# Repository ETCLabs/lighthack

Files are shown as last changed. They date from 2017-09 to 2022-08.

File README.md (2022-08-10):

# #lighthack
This repository contains the source and documentation for **#lighthack**, an educational project designed by ETC users and employees to engage with the DIY community.

#lighthack is a community-supported initiative, and your fellow #lighthackers are your first resource for help!

The #lighthack project is centered around Arduino-based hardware devices that users assemble from scratch. The Arduino connects via a USB COM port and then communicates via OSC with ETC's Eos software.

Eos supports this functionality on consoles running Windows 7 embedded or higher and ETCnomad for Windows in software version 2.6.1 and newer, and on ETCnomad for Mac in software version 2.7.0 and newer.

_Support for XPe-based consoles or XP computers is not planned for this project. If you do not know the version of embedded Windows your console uses, [check this link](https://support.etcconnect.com/ETC/Consoles/General/What_Version_of_Windows_is_my_Console_Running) for identifying information._

## test tools/usb_test
This is the first Arduino sketch to load - it helps to ensure that the Arduino is communicating successfully with Eos. This is also a good point to return to if you want to re-confirm the Arduino-Eos connection later on.

## #lighthack box 1
**#lighthack box 1** is a kit project with two encoders, three buttons and a 2x20 display. This kit is available for purchase directly from ETC's [US](https://shop.etcconnect.com/) and [EU](https://shop.etcconnect.eu/) online shops, but you can also find all of the parts directly from suppliers online. This project is located in the box_1 subfolder. This folder contains an assembly instructions document which also contains the parts list. It also contains the Arduino sketch and other supporting documentation.

[Supported OSC Commands](https://github.com/ETCLabs/EosSyncLib/blob/master/Supported%20OSC%20Commands.pdf)

## About this ETCLabs Project
#lighthack projects are designed to interact with ETC products, but they are not official ETC hardware or software. For challenges using, integrating, compiling, or modifying items in this project, we encourage posting on the [Issues page](https://github.com/ETCLabs/lighthack/issues) or on the [#lighthack forum](https://community.etcconnect.com/etclabs/f/lighthack). Again, #lighthack is a community-supported initiative, and the #lighthacking community is the best place to ask for help!

## Dependencies
Requires the Arduino OSC parsing library maintained by the great folks over at [CNMAT](https://github.com/CNMAT/OSC). The assembly instructions documents contain details on how to add this to your Arduino project.

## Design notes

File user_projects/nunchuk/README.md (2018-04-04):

#  Lighthack Nunchuk Assembly Instructions

<a href="http://www.youtube.com/watch?feature=player_embedded&v=b4YxDby04tY
" target="_blank">YouTube Video</a>

## Parts List

| **ETC PN** | **Vendor PN** | **Qty** | **Description** |
| --- | --- | --- | --- |
| 4201B9001 | Mouser 782-A000066 | 1 | Arduino Uno R3 |
| W6378 | | 1 | USB Cable, A to B |
| | Adafruit 342 | 1 | Nunchuk Remote Controller Attachment For Nintendo Wii |
| | Adafruit 345 | 1 | Nunchucky (Wii Nunchuck breakout adapter) |
| 4201B7001 | | 1 | Wire Solid Core 22AWG/0.65mm2 2-3&#39;/60-90cm |
| 4201A4001 | Hammond 1591U | 1 | Enclosure with lid and screws |

## Tools

- Wire strippers and cutters
- Soldering iron and solder

## Software

- Arduino Integrated Development Environment (IDE). Download from [https://www.arduino.cc/en/Main/Software](https://www.arduino.cc/en/Main/Software)
- Arduino sketch for Nunchuk. Download from [https://github.com/ETCLabs/lighthack](https://github.com/ETCLabs/lighthack)
- Arduino OSC library. Download from [https://github.com/CNMAT/OSC](https://github.com/CNMAT/OSC)
- Arduino to Eos Test Application. Download from [https://github.com/ETCLabs/lighthack](https://github.com/ETCLabs/lighthack)

## Test the Software

It is recommended that you test the Arduino before starting the assembly of the enclosure.

1. Download the source code from https://github.com/ETCLabs/lighthack, and extract the .zip file (or clone the repository if you're git-savvy!).

1. Open the Arduino USB Test sketch  (lighthackmaster\test\_tools\usb\_test\usb\_test\_sketch\usb\_test\_sketch.ino) in the Arduino IDE.
1. Before the sketch will compile, we need to add additional code (called a &quot;library&quot;) so that the Arduino knows how to speak OSC. Download the library as a .zip from [https://github.com/CNMAT/OSC](https://github.com/CNMAT/OSC).
1. In the Arduino IDE, select **Sketch &gt; Include Library &gt;Add .ZIP Library...** and select the OSC zip file you downloaded
1. Press the check mark to verify your sketch.

1. Connect the Arduino to your computer using the USB cable.
1. The Arduino IDE will automatically detect your Arduino Uno and select it. You can verify this in the Tools menu:

1. Press the arrow to upload your sketch to the Arduino.

1. After the sketch has been loaded, the Arduino&#39;s lights should have the L and ON lights solid and the TX light blinking once per second:

1. Launch Eos software, open Tab 99 Diagnostics, and look for messages that read:
```
        OSC USB Device Handshake Complete [OK]
        OSC USB Device Handshake Initiated [ETCOSC?]
```

The TX and RX lights should blink in sequence once per second.
Press `Incoming OSC` and you should see repeating messages of `[OSC Packet] /eos/ping` and a number counting up

These messages indicate that your Arduino and Eos are talking to each other.

The RX LED on your Arduino should also start blinking.

11. Exit the Eos software.
1. Now, load the main nunchuk.ino code. If you&#39;ve added the OSC library properly, the verification will be successful.
1. Press the arrow to upload your sketch to the Arduino.
1. After the sketch has been loaded, start Eos again and look for the same Handshake messages. Note that in this mode, the Arduino does not send the repeating Ping messages, and the Arduino&#39;s TX/RX LEDs will only blink once.

If text does not appear, follow the troubleshooting steps at [https://github.com/ETCLabs/lighthack/blob/master/box\_1/box\_1\_assembly\_instructions.pdf](https://github.com/ETCLabs/lighthack/blob/master/box_1/box_1_assembly_instructions.pdf)

## Adding the Nunchuk 

Connect the `3.3v` and `Gnd` pins to the respective Arduino Pins using the jumper wire and soldering iron. Connect Nunchuk `Data` to `SDA` (Analogue 4 on Arduino Uno) and `Clk` to `SCL` (Analogue 5 on Arduino Uno)
Breakout Adaptor
Wiring Diagram
Plug in the Nunchuk, and then powerup the Arduino

## Usage

Press Z as ETC Eos "Next" and C as "Last".

Use joystick to adjust Pan/Tilt on moving fixtures 

Hold down both Z & C for "fine" mode of movement

## Guide to Arduino LEDs



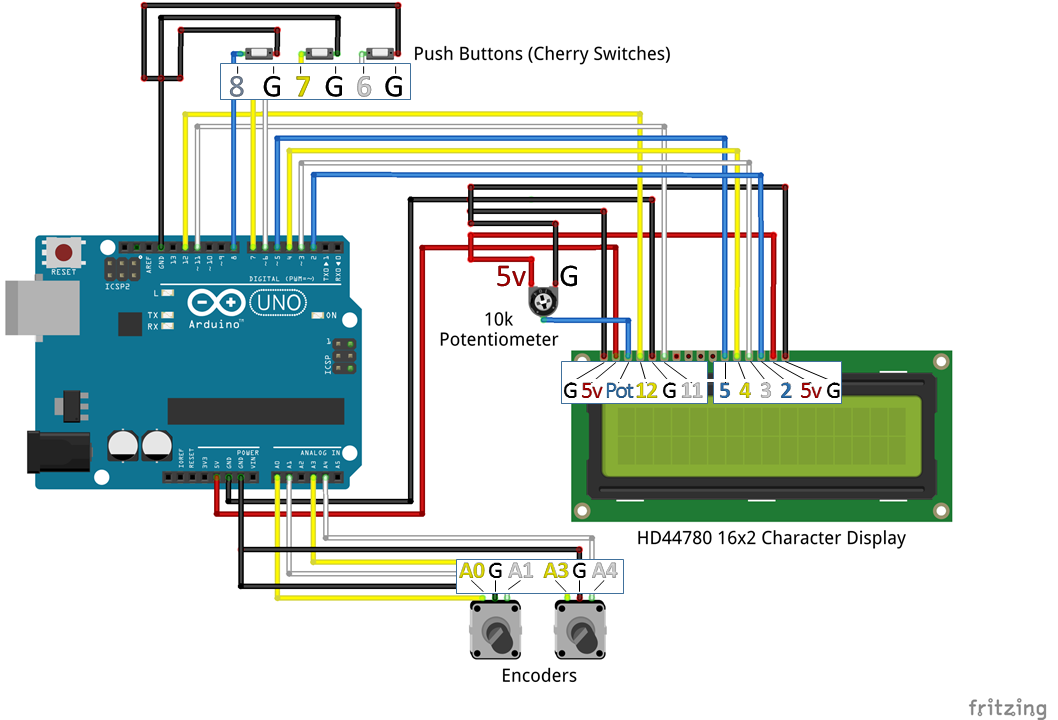
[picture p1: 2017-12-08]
box_1/Hookup_Diagram.png

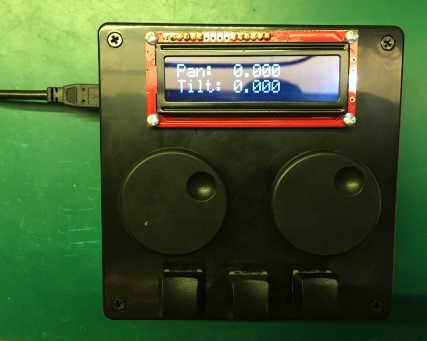
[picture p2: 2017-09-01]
box_1/Box 1.png

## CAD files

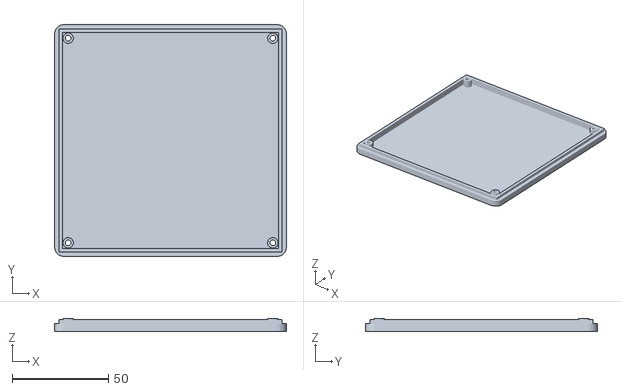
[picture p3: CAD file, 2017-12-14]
box_1/faceplate_model_blank.STL
120.4 x 120.4 x 6.50

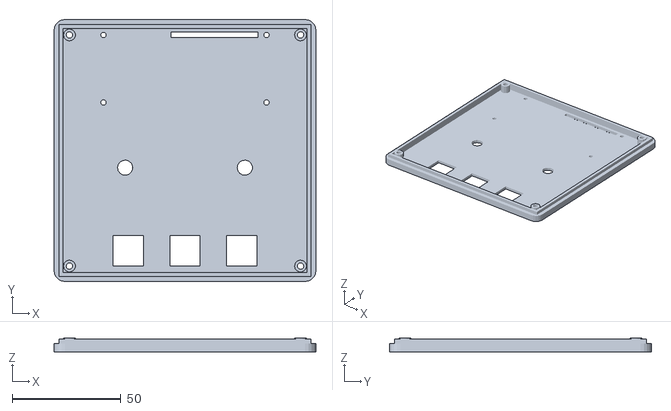
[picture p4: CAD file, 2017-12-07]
box_1/faceplate_model.STL
120.4 x 120.4 x 6.50

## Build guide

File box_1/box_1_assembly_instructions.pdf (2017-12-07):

#lighthack box 1 | | Revision: 07

## Assembly Instructions

Parts List

Part Number | Qty Description
4201B9001 | 1 | Arduino Uno R3
DS221-F | 1 | HD44780 Display Module
S846-F | 3 | Cherry MX Red Key Switch
4152A4039 | 3 | Black Eos® -Style Key Cap
L1243-F | 2 | Rotary Encoder with Panel Mounting Hardware
4201A4003 | 2 | Encoder Knob
4240B7011 | 1 | 10 kΩ Potentiometer
4201B7001 | 1 | Red Wire Solid Core 22AWG/0.65mm² 2-3'/60-90cm
4201B7002 | 1 | Black Wire Solid Core 22AWG/0.65mm² 2-3'/60-90cm
4201B7003 | 1 | White Wire Solid Core 22AWG/0.65mm² 2-3'/60-90cm
4201B7004 | 1 | Yellow Wire Solid Core 22AWG/0.65mm² 2-3'/60-90cm
4201B7005 | 1 | Blue Wire Solid Core 22AWG/0.65mm² 2-3'/60-90cm
J4630 | 3 | 5-position Wago Wire Connector
J4629 | 1 | 3-position Wago Wire Connector
W6378 | 1 | USB Cable, A to B
HW0006 | 10 | Machine screws #2-56x3/16" (~5mm)
HW9489 | 5 | Standoffs #2-56x1/4" (~6mm)
4201A4001 | 1 | Enclosure with lid and screws

Tools

Necessary:

- Wire strippers and cutters
- Soldering iron and solder
- Philips screwdriver
- Drill with 1
| /8" / 3mm,

1
| | /4" / 6mm,
| | 1 /2" / 12mm bits
- Rasp/File or Chisel

Helpful:

- Needle-nose pliers
- X-Acto knife or other sharp knife
- Electrical tape
- Thick double-sided tape

Software

- Arduino Integrated Development Environment (IDE). Download from https://www.arduino.cc/en/Main/Software
- Arduino sketch (code) for box 1. Download from https://github.com/ETCLabs/lighthack
- Arduino OSC library. Download from https://github.com/CNMAT/OSC
- Arduino to Eos Test Application. Download from https://github.com/ETCLabs/lighthack

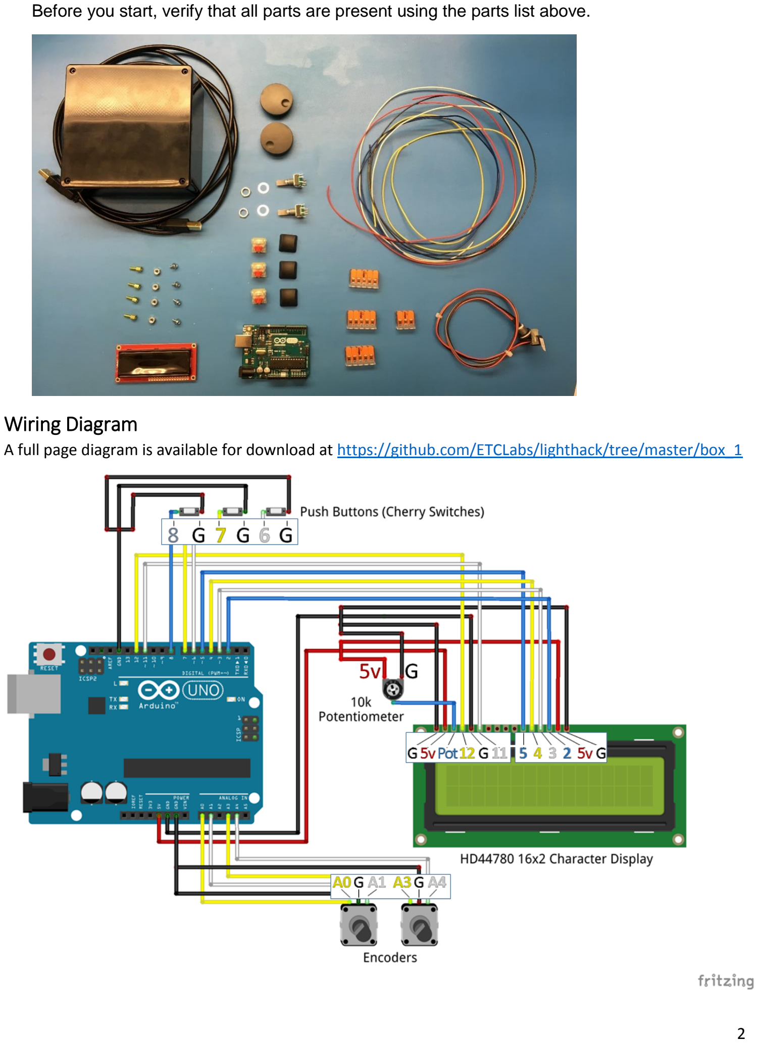
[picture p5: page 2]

Before you start, verify that all parts are present using the parts list above.

## Wiring Diagram

A full page diagram is available for download at https://github.com/ETCLabs/lighthack/tree/master/box_1

## Test the Software

It is recommended that you test the Arduino before starting the assembly of the enclosure.

1. Download the source code from https://github.com/ETCLabs/lighthack, and extract the .zip file (or clone the repository if you're git-savvy!).

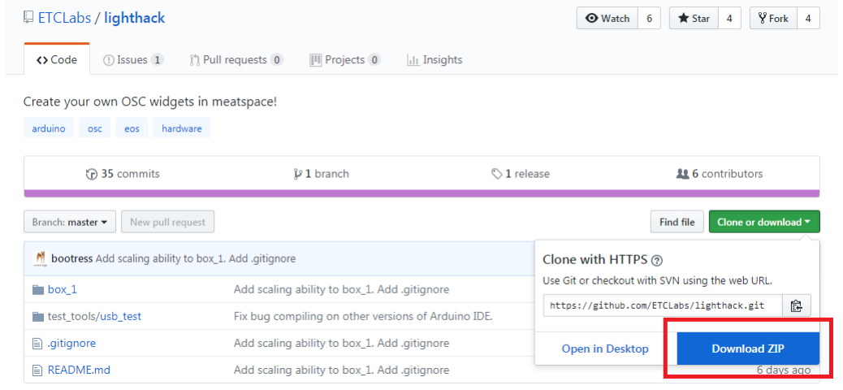
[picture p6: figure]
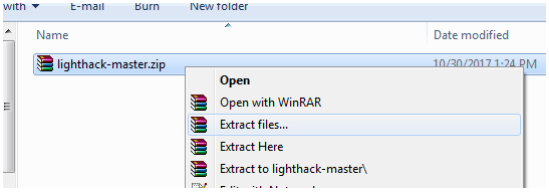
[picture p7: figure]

2. Open the Arduino USB Test sketch (lighthack-master\test_tools\usb_test\usb_test_sketch\usb_test_sketch.ino) in the Arduino IDE.
3. Before the sketch will compile, we need to add additional code (called a "library") so that the Arduino knows how to speak OSC. Download the library as a .zip
from https://github.com/CNMAT/OSC.
4. In the Arduino IDE, select Sketch > Include Library >Add .ZIP Library... and select the OSC zip file you downloaded
5. Press the check mark to verify your sketch.

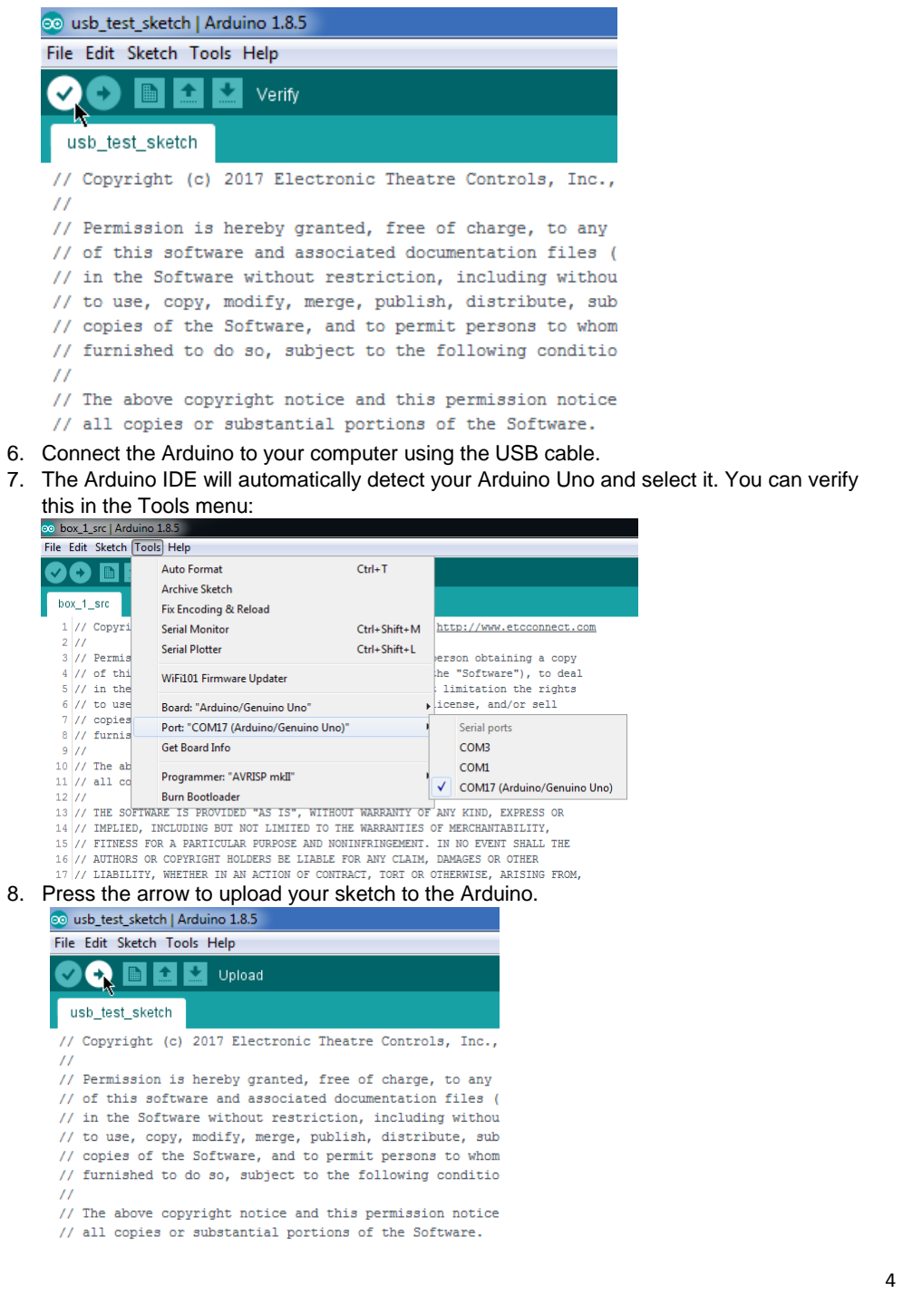
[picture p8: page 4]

6. Connect the Arduino to your computer using the USB cable.
7. The Arduino IDE will automatically detect your Arduino Uno and select it. You can verify this in the Tools menu:
8. Press the arrow to upload your sketch to the Arduino.

9. After the sketch has been loaded, the Arduino’s lights should have the L and ON lights solid and the TX light blinking once per second:

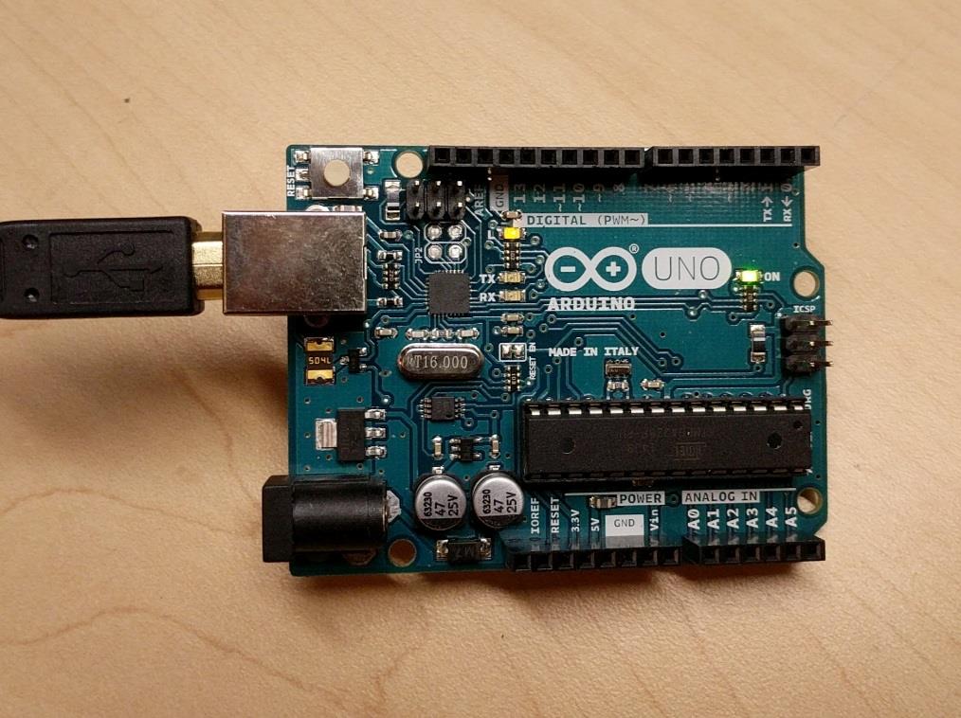
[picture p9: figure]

10. Launch Eos software, open Tab 99 Diagnostics, and look for messages that read:
“OSC USB Device Handshake Complete [OK]”
“OSC USB Device Handshake Initiated [ETCOSC?]”
The TX and RX lights should blink in sequence once per second. Press “Incoming OSC” and you should see repeating messages of “[OSC Packet] /eos/ping,” and a number counting up
These messages indicate that your Arduino and Eos are talking to each other. The RX LED on your Arduino should also start blinking.
11. Exit the Eos software.
12. Now, load the main box_1_src.ino code. If you've added the OSC library properly, the verification will be successful.

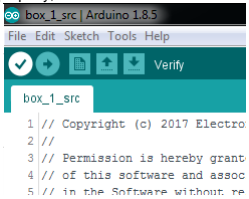
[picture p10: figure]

13. Press the arrow to upload your sketch to the Arduino.

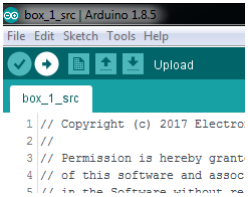
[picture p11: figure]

14. After the sketch has been loaded, start Eos again and look for the same Handshake messages. Note that in this mode, the Arduino does not send the repeating Ping messages, and the Arduino’s TX/RX LEDs will only blink once.
If text does not appear, follow the troubleshooting steps at the end of this document.

## Prepare the Enclosure

15. Print out the paper template, making sure to disable any "fit to paper" or scaling options so that it prints at actual size. The template is found at https://github.com/ETCLabs/lighthack/tree/master/box_1.
16. Cut out the template and lay it over the top of the enclosure lid, using the screw holes or tape to make sure it doesn't move.

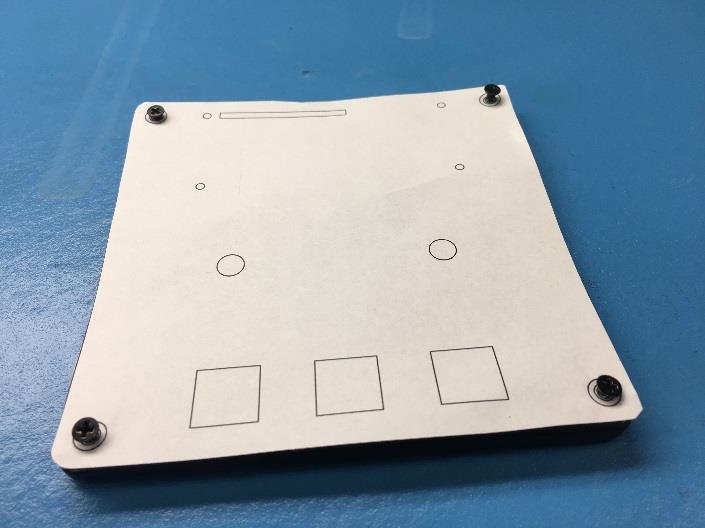
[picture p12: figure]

17. Drill out the holes using the proper size drill bits. Drill starter holes in the square cutouts. For the long rectangular slot, you may want to drill a few holes right next to each other as a starting point for a file.
18. Using this template, the LCD display will be mounted to the outside of the lid. Skip to Step 13 if you want to follow the template. If you would like to mount the display to the inside of the box, cut a rectangular hole in the enclosure lid slightly larger than the face of the LCD screen.

TIP: Don't feel like
drilling and filing? Use
the provided 3D
Printer template to
print a "pre-drilled" lid.

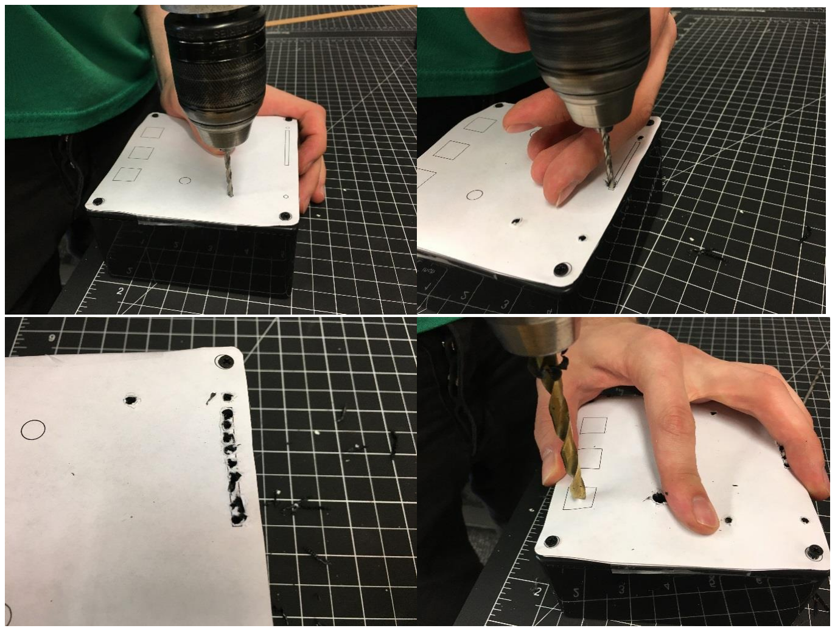
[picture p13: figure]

19. Using a square or rectangular file, file out the square holes and slot (or use your preferred method of making square holes).
20. Test fit the Cherry MX Red switches into the square holes as you file to make sure you have the right size.

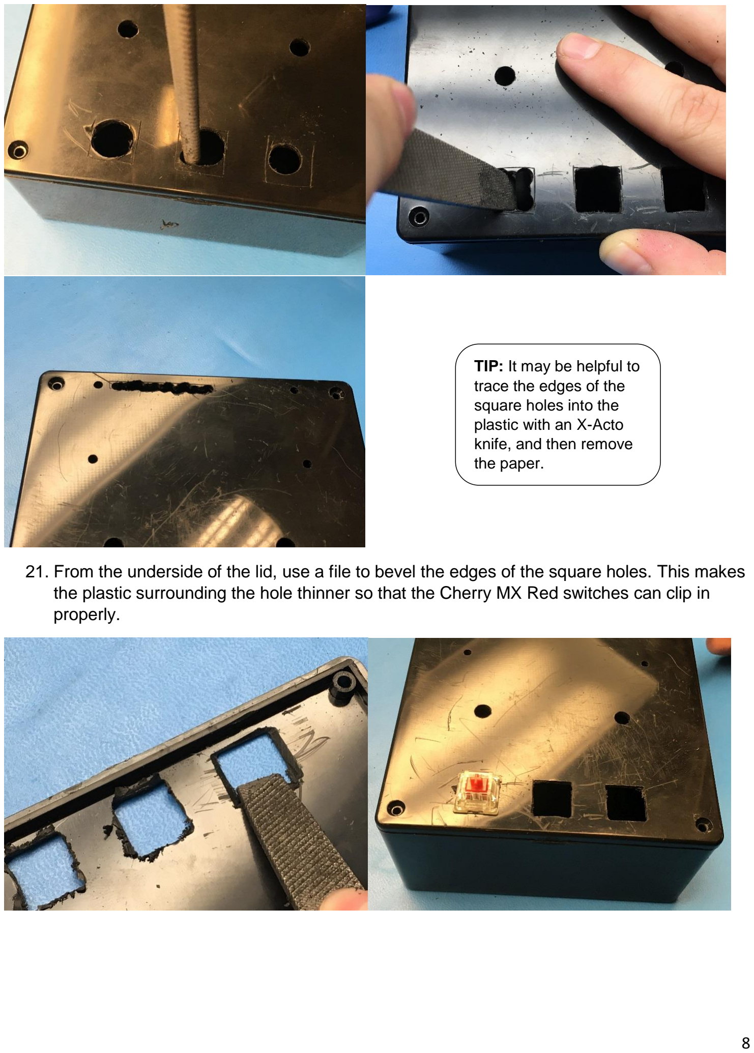
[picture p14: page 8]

21. From the underside of the lid, use a file to bevel the edges of the square holes. This makes the plastic surrounding the hole thinner so that the Cherry MX Red switches can clip in properly.

TIP: It may be helpful to
trace the edges of the
square holes into the
plastic with an X-Acto
knife, and then remove
the paper.

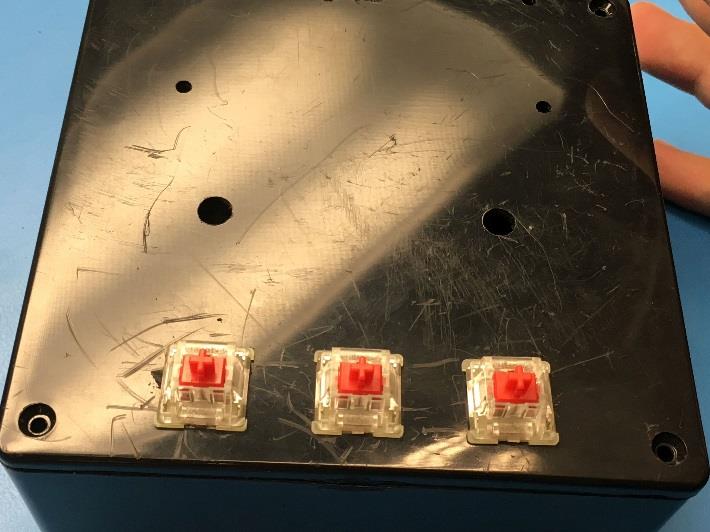
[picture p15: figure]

22. Line up the Arduino with a side of the box in order to estimate the location of the hole. We've found a good location to be 1"/25mm in from a corner and ½"/12mm up from the bottom. Use a ½"/12mm drill bit to drill a hole for the USB connector. Make sure you can connect a USB cable to your Arduino through the hole.
23. Drill a hole for the USB connector. If desired, add a second 1/2" hole to mount the potentiometer.

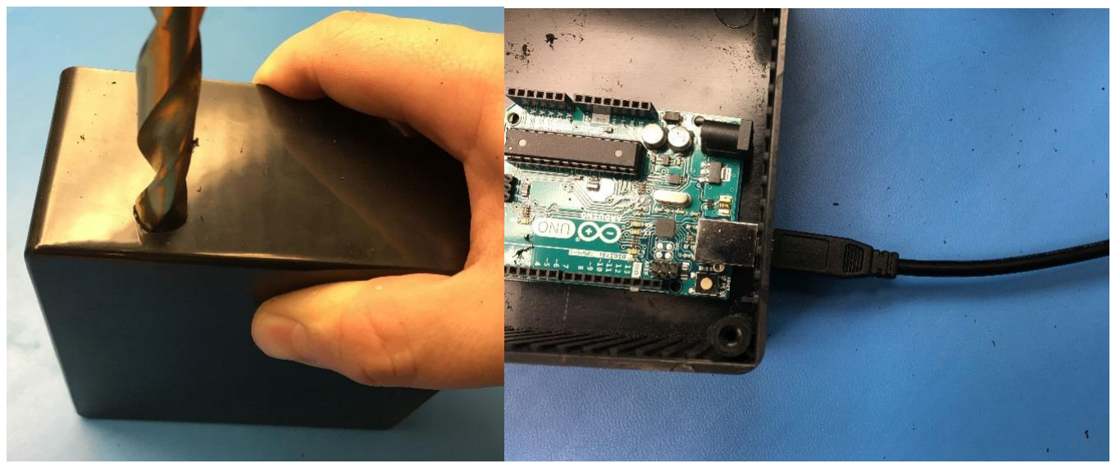
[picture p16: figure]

## Connect the Electronics

24. Cut appropriate lengths of wire to connect the three buttons and two rotary encoders to the Arduino as shown in the wiring diagram. The wire colors in the wiring diagram are a suggestion. The wire colors in your kit may vary.
25. Strip approximately ½"/12mm of insulation from either side of each length of wire.

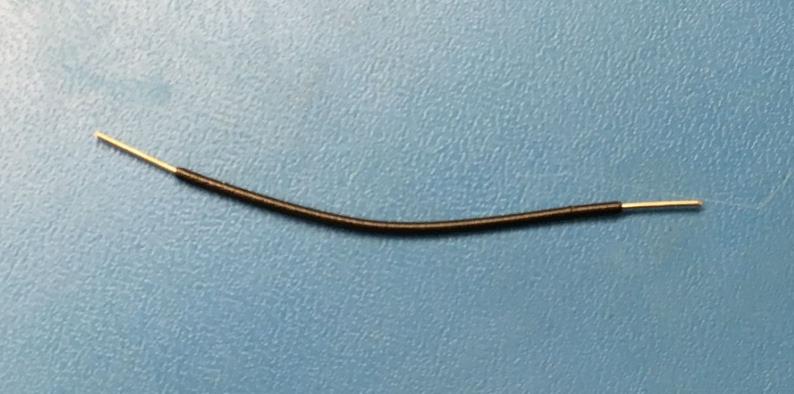
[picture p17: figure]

26. Solder one end of each wire length to pins on the rotary encoders and key switches.
27. Use the Wago connectors where multiple black (ground) wires need to be connected together. Only three of the five leads on the encoders need to be connected, as shown. You will want to have the key switches inserted into the enclosure lid already when you do this.

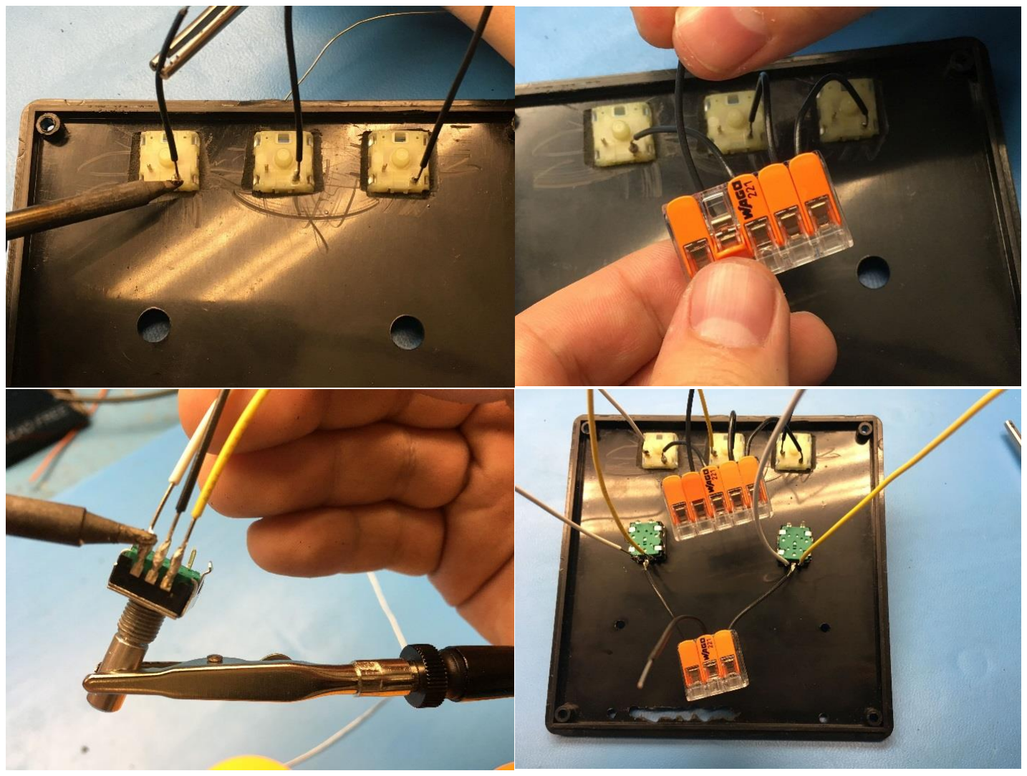
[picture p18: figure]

28. Cut appropriate lengths of wire to connect the display and contrast adjustment potentiometer to the Arduino as shown in the wiring diagram.
29. Cut off the connector from the potentiometer.

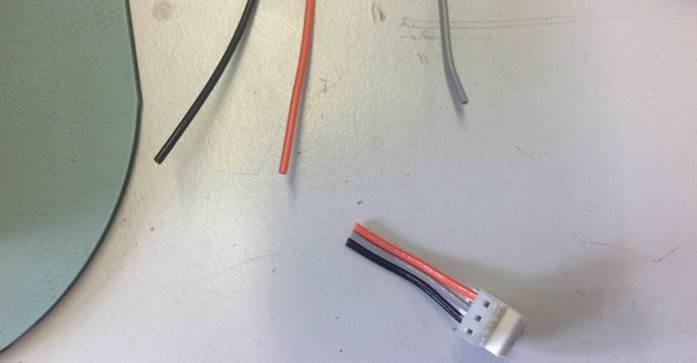
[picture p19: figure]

30. If you are mounting it to the box, thread on the rubber washer and locking ring, string the wire through the box, then tighten with the nut. This has to be done before soldering.
31. Strip approximately ½"/12mm of insulation from either side of each length of wire.
32. Solder one end of each wire length to the display as shown.
33. Connect the middle pin of the potentiometer to the display as shown.

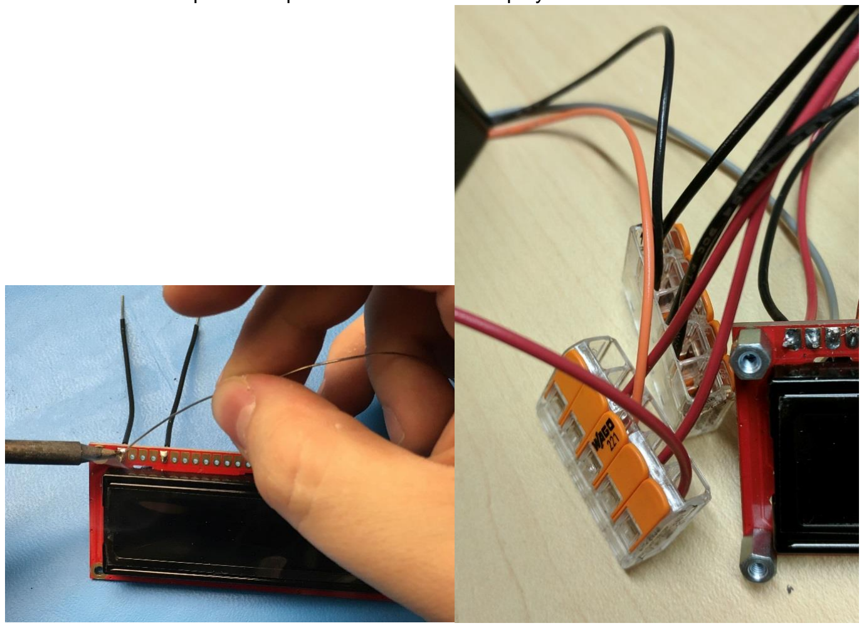
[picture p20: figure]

34. Connect the free end of each wire to the appropriate pin on the Arduino as shown in the wiring diagram.

35. Before mounting everything in the enclosure and finishing the assembly, the electronics should be tested. Connect the Arduino to a Win7 Eos Family console or a computer running ETCnomad.
36. Test the device by patching a moving light, selecting it and using the encoders to modify the pan and tilt values. Check to make sure that the "next" and "last" buttons cycle through the channels and the "fine" button switches between coarse and fine adjustment.

## Finish the assembly

Now that your module has been tested, it's time to put it in the enclosure.

37. Insert the two encoders through the holes from the inside of the lid.
38. Use the included panel mounting nuts and washers to secure the encoders.

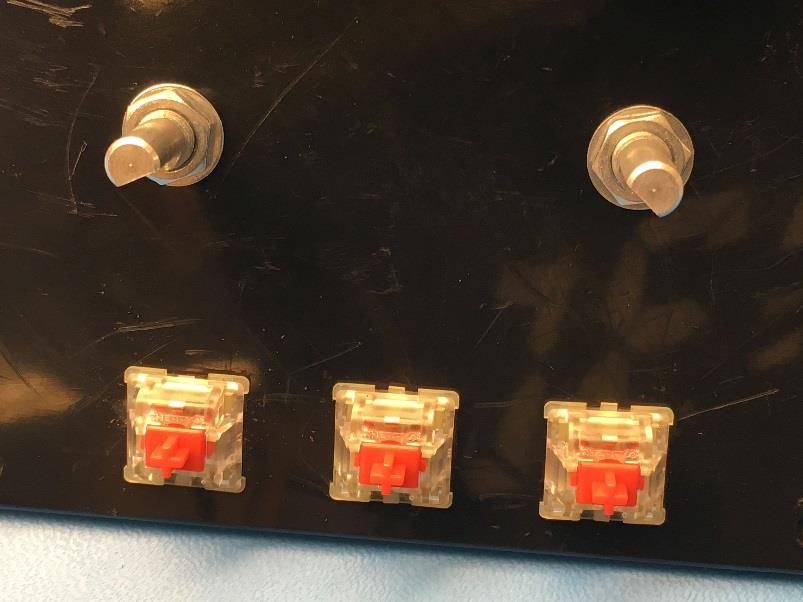
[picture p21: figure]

39. Disconnect the screen from the Arduino and feed its wires through the rectangular slot. If mounting to the inside of the box, you would instead mount the LCD screen inside the lid using the standoffs on the underside of the lid.

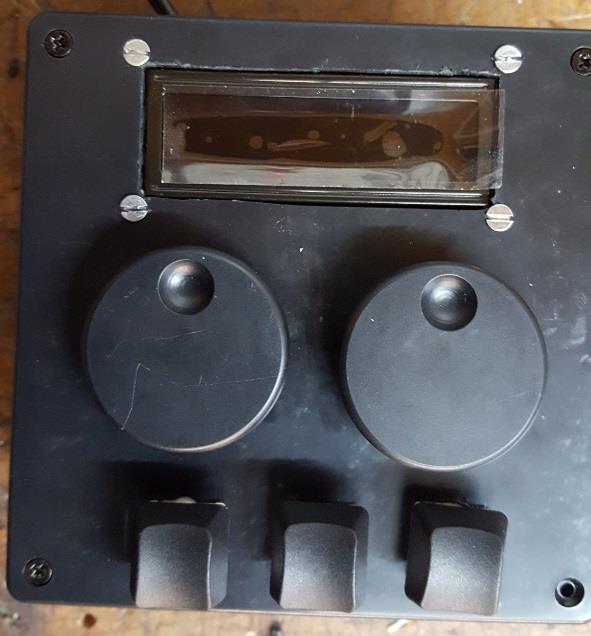
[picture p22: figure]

40. Secure the screen in place using eight #2-56 machine screws (four from the top, and four from the bottom) and either the ¼" (~6mm) or ½" (~12mm) standoffs. Extra screws and standoffs are provided.

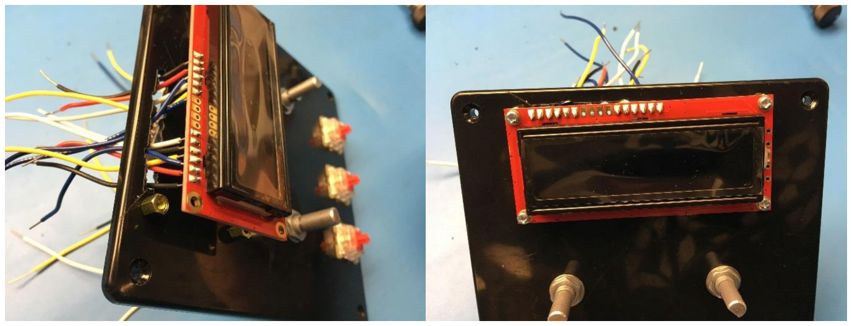
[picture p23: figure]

41. Place the Arduino into the enclosure such that the USB connector is aligned with the hole you drilled earlier.
42. Secure the Arduino using double-sided tape or your preferred method.

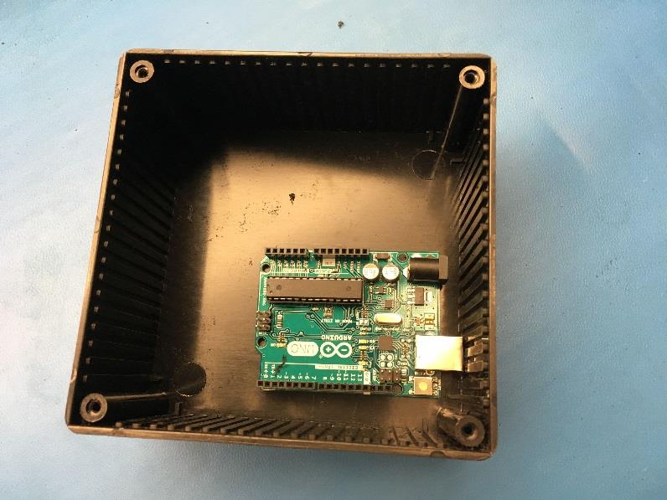
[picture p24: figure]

43. Reconnect all of the wires to the Arduino, referring to the wiring diagram.

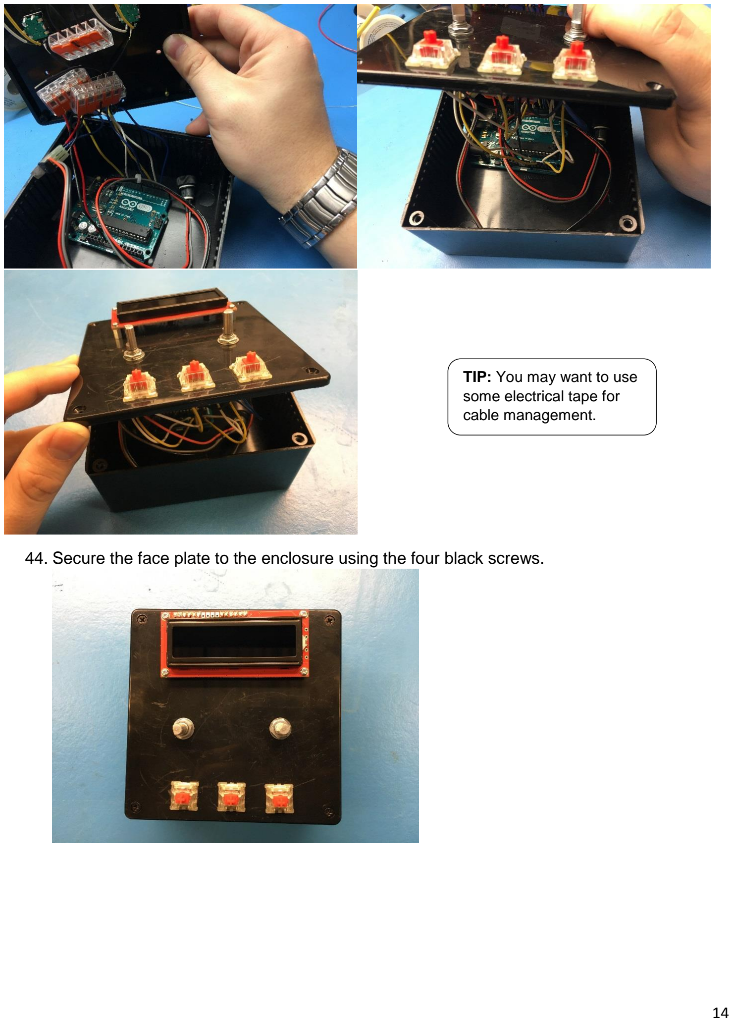
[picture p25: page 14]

44. Secure the face plate to the enclosure using the four black screws.

TIP: You may want to use
some electrical tape for
cable management.

45. Press-fit the keycaps and encoder finger wheels onto the key switches and encoders.

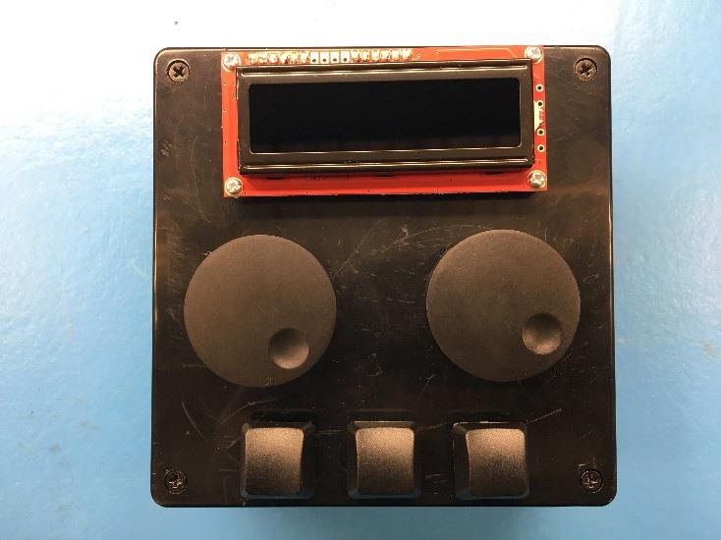
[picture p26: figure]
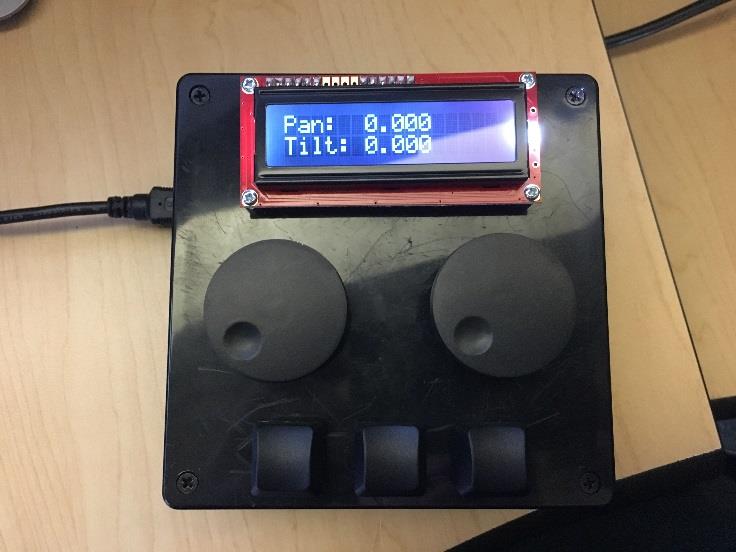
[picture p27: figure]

46. Re-test the module to make sure everything still works. Congratulations! You're done.

## Troubleshooting

Problem | Possible solution
Arduino software displays an orange error message when I try to verify using the check mark icon | Verify that the OSC library is installed using the procedure discussed in the Test the Software section.
Device mostly works but a button or an encoder is not working | Check the solder connections for cold or broken joints. Check the connections to the Arduino. Make sure the button or encoder is connected to the proper Arduino pins as shown in the wiring diagram.
One or both encoders are reversed | Look near the top of the source code (box_1_src.ino) for lines that say "#define PAN_DIR FORWARD" and "#define TILT_DIR FORWARD". To reverse the direction of an encoder, set the corresponding line to REVERSE, i.e. "#define PAN_DIR REVERSE".
Screen "glitches" or displays strange characters | Check the screen's solder connections for cold joints. Check the screen's connections to the Arduino. Make sure no connections are loose or disconnected and that the connections are as shown in the wiring diagram.
Screen is all black or all white | Make sure the contrast potentiometer is connected to the screen as shown in the wiring diagram. Make sure the Arduino is powered on and the code is loaded. Arduino power can be verified by a green "ON" LED located next to the Arduino UNO logo. Turn the contrast potentiometer until text displays on the screen.
Device is not recognized by Eos Family device | Make sure the version of Eos or ETCnomad software you are running supports OSC-over- USB. Make sure the Arduino driver pack is installed on the device running ETCnomad software. Use the usb_test (https://github.com/ETCLabs/lighthack/tree/master/test_tools/usb_test) sketch from the Github repository to narrow the problem.

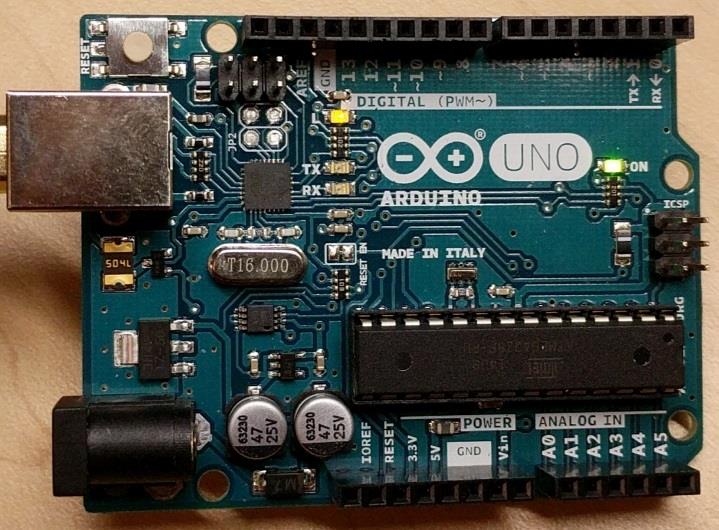
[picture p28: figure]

## Arduino LED Guide

LEDs to be aware of:
- ON (green): power presence
- L (amber): presence of code
- TX (amber): transmitting data
- RX (amber): receiving data
When you plug the Arduino in for the first time:
- On: solid
- L: possibly blinking
- TX: off
- RX: off
When you are loading sample or test code to the Arduino:
- On: solid
- L: will go off
- TX: flashing then solid
- RX: flashing then solid
When you have loaded the USB test sketch, but are not connected to a compatible Eos Family device:
- On: solid
- L: solid
- TX: heartbeat
- RX: off
When you have loaded the USB test sketch, and are connected to a compatible Eos Family device:
- On: solid
- L: solid
- TX: heartbeat
- RX: hearbeat
When you have loaded the Box 1 sketch, but are not connected to a compatible Eos Family device:
- On: solid
- L: will go off
- TX: flashing then solid
- RX: flashing then solid
When you have loaded the Box 1 sketch, and are connected to a compatible Eos Family device:
- On: solid
- L: solid
- TX: flashes when you move pan/tilt or hit next/last on the box
- RX: flashes when you move pan/tilt on Eos Family device

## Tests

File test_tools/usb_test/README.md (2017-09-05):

# USB Test Sketch
This folder contains a troubleshooting tool to verify the line of communication between an Arduino and the Eos software. Once connected with Eos, it sends a series of OSC "ping" messages which are visible in the Eos diagnostics tab. Follow these steps to use it:

1. Burn the sketch to your Arduino using the Arduino IDE.
2. Start the Eos Family software, and connect your device to the machine running Eos (if not the same machine).
3. Navigate to the Eos diagnostics tab ([Tab & 99]). You should see log messages about an OSC handshake completing:

handshake messages

4. On the diagnostics tab, click the button labeled "Incoming OSC (off)" to turn on display of OSC messages. You should see a ping message coming from your device once per second with an incrementing number argument:

ping messages

If this doesn't work, there is a non-hardware-related problem. Make sure the Arduino USB drivers are installed on your target machine. Check the Device Manager to make sure the Arduino is being recognized correctly.

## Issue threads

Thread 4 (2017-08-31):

Can't get anything to work

jpgagnon73, 2017-08-31:
So, I've wired it all up, several times.  Loaded the sketch with OSC library several times, no errors.  I only get 1 line of squares on the display and not one ounce of control.  I am running an Uno.  is v3 vital to this project working?  Is there something missing in the code??
Thanks
JP

bootress, 2017-08-31:
:confused:

We have tested the code as it exists here with Nomad PC and several consoles. Note that there is no support for Nomad Mac yet. Some things to try:

- Troubleshooting section at the end of the assembly instructions document
- Watch the Eos logs ([Tab] & 99) when you connect the Arduino to the console. You should see messages scroll by that look similar to:
  - OSC USB Device Connected (Handshake Required)
  - OSC USB Device Handshake Initiated [ETCOSC?]
  - OSC USB Device Handshake Complete [OK]

  This will verify that basic OSC USB connectivity is working between the device and the Eos software. Then you'll know that it's a hardware/wiring issue.

 I took a look at the differences between Uno original, R2 and R3 [here](http://startingelectronics.org/articles/arduino/uno-r3-r2-differences/); We tested on an R3, but I see nothing that would make the code function differently on an R2 or earlier.

jpgagnon73, 2017-08-31:
Ok, well I've been doing it on a mac only at this point.  i will try on my dedicated nomad PC at home.  one question, does the display show anything until it connects to EOS?

jpgagnon73, 2017-08-31:
And I just verified that the UNO i'm using is an R3.  Sometimes I need to open my eyes more.

bootress, 2017-08-31:
Yes, if there is no Eos connection there should be a default display which looks like:

```
Pan:  0.000
Tilt: 0.000
```

If you are getting a line of squares, I strongly suspect a wiring issue. Double check the wiring and especially the solder joints (cold solder joints tripped us up once while we were testing).

jpgagnon73, 2017-08-31:
yeah, I just get squares.  I am going to resolder the whole thing.  Curious, can the display be tweaked to show
              PAN          TILT
            0.000         0.000

I think this would make more sense in terms of the layout of the encoders.  Also, any reason we could use the encoder push down function to toggle the fine/coarse?

bootress, 2017-08-31:
The beauty of this being a DIY project is that you can make it do whatever you want! Our code is just a guideline / jumping off point. Your changes are totally doable with just a few tweaks to the code (the encoder push down change might require some new wiring too).

jpgagnon73, 2017-08-31:
I am hoping it will be easy to change the text.  i would love to make this a 3 encoder box, so it will be more useful to mod to do other ML attributes down the road.  Thanks for your hard work on this.  Hopefully I can get it all working once I re-solder it all.

bootress, 2017-08-31:
Glad to help, and good luck! I'm told there will soon be a forum dedicated to this project on the ETC Community, so when that goes live I encourage you to post your modifications so other DIYers can take note!

Closed 2017-08-31.

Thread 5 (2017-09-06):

Some Arduino hardware not working.  Various responses

Druuka, 2017-09-06:
USB OSC Arduino Device List

Arduino Uno Genuine			Yes
Osepp Uno R3 Plus			Does not see USB device
Arduino 101 Genuine			No
Arduino Ethernet with Arduino FTDI 	Yes
Arduino M0				Sees as USB Serial device but M0 not handshaking
Arduino Due				Tries to handshake on programming port but Due tries on native port
Generic Nano ATMega328			Does not see USB Device
OSEPP Nano ATMega328			Does not see USB Device
Gravitech Nano ATMega328		Does not see USB Device
Teensy 3.2				Does not See USB Device
Arduino ATMEGA2560			Yes

bootress, 2017-09-06:
Thank you so much for doing this testing. To add the additional context from your facebook comment, these are results from testing on an Ion Win7 console, right?

I found out that we are only installing a subset of the Arduino driver pack onto our consoles with the new Eos versions. This is probably the reason for your "Does not see USB Device" results. I am going to see what we can do about this in the future.

Druuka, 2017-09-06:
Yes this was with a Windows 7 based Ion console for testing.  I agree.  It would be great if they could include at least a couple others.  Something small like the Nano or Mini/pro mini or micro.  The Teensy line are also very popular because they are fast and very versatile.  Some of the more obscure (101, M0, Due) are nice units but not part of the core arduino that people own. Most of the Generic/non arduino brand units use the FTDI232 chipset which is its own set of drivers.

sstaub, 2017-09-06:
Many Arduino clones and ESP32 boards uses the CH340g USB chip, drivers can found on [http://sparks.gogo.co.nz/ch340.html](url). The last updates of the OSC library was done a year ago and only teensy boards were updated. The newer arduino boards with atmel samd21 (e.g. Arduino Zero) are not supported yet.

sstaub, 2017-09-06:
I tested following boards on WIN10 (Apple MacBook with Parallels and Bootcamp)
- Arduino UNO original OK
- Arduino Nano Clone with FTDI OK
- Arduino Nano Clone with CH340G OK
- Arduino Micro Clone (native USB) OK
I will test some other boards next time and report the results.

Druuka, 2017-09-06:
sstaub,
Did you install drivers for those on the computer?  If so they may not work with a console.  I think we need to get a list of what works with the default drivers provided with the console.

sstaub, 2017-09-06:
Yes, I installed the driver for my macOS (I use PlatformIO for coding on my MacBook) and WIN10
for use with ETCnomad.
I don't know if the drivers work on the console, but if you look on ebay or aliexpress you find many boards who use the cheaper CH340G USB chip instead of the FTDI chip. So maybe etc will install also this driver on the consoles.

Druuka, 2017-09-06:
I'm trying to come up with a list of what does and doesn't work with the default drivers so ETC can decide what additional drivers they want to install on the consoles.  For Nomad users they can install whatever drivers they want. :)

jpgagnon73, 2017-09-07:
So, I just tried testing mine on an Element XP console and it does not work.  such a bummer.  But at least it works with Nomad.

jpgagnon73, 2017-09-26:
I can confirm the Arduino Nano works on Nomad if you install the specific driver for for it on the console.  This will work for my scenarios very well.

kcrayn, 2017-12-08:
I'm trying to get a Genuino Micro working with Nomad under Win10 but not having any luck. It works perfectly using an UNO. Do I need to change anything in the code (I'm specifically trying to get the usb_test to work)

sstaub, 2017-12-09:
Working with an micro clone without problems, have WIN10 recognized your micro. Will see it by nomad (open tab 99 for analyzing).
Have also a look to the new #lighthack forum.
[https://community.etcconnect.com/etclabs/f/lighthack](url)

kcrayn, 2017-12-11:
I didn't realize there was a #lighthack forum, I've made a post over there with more details.
Thank you

TfairleyHO, 2018-05-04:
I am trying to use a SparkFun "RedBoard" that I got for free with a class I took, but when running the test sketch I can get Nomad to recognize the USB but it won't receive the OSC message. I tried plugging it into our Element (win7) but it would not even recognize the usb device. The redboard has an ATMega328p and FTDI1533. I thought it would work fine since it is supposed to be very similar to the UNO. This might be the wrong thread to post this but I thought it was a hardware issue related to the main topic. Let me know if anyone has any ideas.

Druuka, 2018-05-04:
TfairleyHO,   If you look at my post above I couldn't get any of the atmega328 based boards to be recognized by the console.  The console identifies boards based on how the USB/Serial connection is created Some of the devices show up as a usbserial rather than serial and these seem to be the units that the console is not attempting negotiations with.

sstaub, 2018-05-04:
Maybe it is the driver, maybe it is a problem with the VID/PID of the the board.

TfairleyHO, 2018-05-07:
So I managed to change the PID/VID using the FT-Prog tool from FTDI. I changed it to match the PID/VID for the Uno but I still needed to change the PID/VID in the FTDI driver and force it to use that driver since it wouldn't work with the UNO driver. The main difference seems to be that the Uno uses the FT232RL FTDI chip but the RedBoard uses the FT231XS Chip.

I can successfully upload the Handshake test, and now Nomad seems to recognize it as an OSC device since it puts out a lot of OSC strings. Now however it is giving me the following error multiple times: "Read Failed with result 17, error 0x1". Then it ends with EOS attempting the Handshake but receives nothing in return. I feel like I am closing in on a solution but still need some help. There is a field in the FT-Prog tool to change the Manufacturer from it's default (FTDI) in the EEPROM. Maybe I need to change that. Not sure what is causing EOS to fail out but it must have something to do with the different FTDI chips.

sstaub, 2018-05-07:
Have you changed the PID/VID also in the boards.txt of the Arduino IDE?
I have had also problems with FTDI chips and their clones, sometimes they work sometimes not.
Maybe the driver will be overridden when you install the console software.
Best way seems to use chips with native usb, like Arduino Mikro etc. because
they work without any external driver on newer systems.

TfairleyHO, 2018-05-07:
The PID/VID on the EEPROM and the Driver now match the PID/VID in boards.txt so the IDE now recognizes it as an UNO. I don't really see how changing boards.txt would affect how EOS interacts with it anyways. I wonder if I need to modify the UNO driver to work with this chip, or vice versa edit the FTDI driver so that it acts like an UNO. Has anyone had experience with boards using the FT231XS?

TfairleyHO, 2018-05-08:
What driver do you use for your nano-clone, and what PID/VID doe the Nano use? I am especially interested in the Clone using FTDI. If I switch the PID/VID to the UNO I can get EOS to recognize it as an OSC device but it doesn't seem to be able to communicate over USB with it. I have a few other things that I am going to try and I will let you know what happens.

TfairleyHO, 2018-05-08:
Anyone know if there is a specific list of PID/VIDs that Eos will listen too?

benjaminauer, 2022-09-15:
Cant get this working with Arduino Leonardo.
No handshake. Eos 3.1.3

sstaub, 2022-09-15:
@benjaminauer I think Leonardo will not work on Windows.  Only Arduino UNO and MEGA is supported official.

benjaminauer, 2022-09-16:
@sstaub you are right. UNO works just fine.
do you know if a request for more support was every brought to etc?
and you know that Leonardo / atmega32u4 works on mac systems?

sstaub, 2022-09-17:
I can remember that 32u4 boards works on macos.
There was an EOS feature request for supporting Teensy and Raspberry Pi Pico boards. On macos I prefer Raspberry Pi Pico boards using https://github.com/earlephilhower/arduino-pico
with the master branch of the OSC library which supports the board.

benjaminauer, 2022-09-17:
Thanks for the hint.
I am looking for the smallest formfactor, thats why i tried the atmega32u4 based dfrobot beetle.
will possibly try the beetle RP2040.
my teensy did work with NOMAD windows 10 but not GIO windows 7. ever had succes with a pico board and GIO windows7?

sstaub, 2022-09-17:
On consoles only Arduino UNO and MEGA definitely works. Maybe other boards works on consoles which works with Windows 10 like Apex and newer Element 2, but this is not tested. Maybe I work on the new Apex consoles in November were I can try.

jamiejcole, 2023-10-28:
Any update on this? I have a win7 element 2 console and my arduino uno clone is not being recognised at all in diagnostics page. It's using the CH340 chipset, really struggling to get this to work. Is there any way i can install the drivers onto the console?

sstaub, 2023-10-28:
@jamiecole No! Use an Original Arduino UNO or MEGA.

jamiejcole, 2023-10-29:
> Any update on this? I have a win7 element 2 console and my arduino uno clone is not being recognised at all in diagnostics page. It's using the CH340 chipset, really struggling to get this to work. Is there any way i can install the drivers onto the console?

Update on this, was able to install the correct drivers by:
- loading into the console ECU,
- spamming shift to open the sticky keys menu
- clicking the hyperlink on the prompt to open control panel
- open device manager from control panel
- find the COM port for the Arduino
- insert usb with extracted .zip folder for windows 7 CH340 drivers, downloaded from [this page](https://www.wch-ic.com/downloads/CH341SER_ZIP.html)
- click update drivers
- select update from local file
- find extracted driver folder on USB
- install drivers
- exit out of all windows and launch EOS primary
- COM4 port is now recognised and can talk to Arduino via OSC over USB

sstaub, 2023-10-30:
@jamiejcole Yes, you can install driver on your console, but it is possible that you will loose your warranty.

geocom, 2025-02-27:
Have found the fix for Teensy 4's on etc consoles. Takes a bit more than the Teensy 3.2 and testing is not helped by windows caching the device so if this doesn't work for you, you may need to look into changing the serial number this is because of how the consoles are locked down you cant remove the cache(at least I couldn't as you cannot get administrator level access) so the only option is to change the serial number as you need the PID/VID to remain the same.

Changes below.
usb_desc.h
PID/VID needs to change lines as per normal for a teensy 3.2
NUM_INTERFACE needs to be changed to 2
EXPERIMENTAL_INTERFACE need to be commented out

usb.c
Uncomment
//USB1_PORTSC1 |= USB_PORTSC1_PFSC; // force 12 Mbit/sec

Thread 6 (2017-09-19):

Simpler LCD Screen

jpgagnon73, 2017-09-19:
I would love to try and use the 16x2 display from this link here:  http://wiki.sunfounder.cc/index.php?title=I²C_LCD1602#Step_3:_Copy_the_code

This uses Pins A4 &A5 for all data to the lcd instead of D2-5 +D11+12.  Much simpler build.  But I'm having problem getting it to work in the sketch.  Any help would be greatly appreciated.

I know I would have to change the Encoders to use Pins A0+A1 and A2+A3  (not sure why A2 and A5 were originally used in the sketch since nothing is connected to them physically.)

JP

bootress, 2017-09-19:
Looks like you will need to download and include the LiquidCrystal_I2C library (seems to be a separate library from the LiquidCrystal one we use)

> (not sure why A2 and A5 were originally used in the sketch since nothing is connected to them physically.)

I think it's cruft that was originally intended to read the encoder's pushbutton, which we ended up not using in our example. I'll rip that out in the next update. For a quick fix, you can probably simply move the second encoder to pins A2+A3, and change lines 452 and 453:
```Arduino
initEncoder(&panWheel, A0, A1, 9, PAN_DIR);
initEncoder(&tiltWheel, A2, A3, 10, TILT_DIR);
```
9 and 10 are just two unused pins in the example. Then follow their instructions for including the LiquidCrystal_I2C library and copy their example code for initting the LCD (disclaimer: I have not tested this)

jpgagnon73, 2017-09-19:
When putting it into the sketch I kept getting errors like VOID already defined or other things.  I got it to work on it's own from the sample sketch they provided.  Something I'm missing I guess and not sure where to look.

jpgagnon73, 2017-09-20:
OK, found my issues.  Mostly it was where I was putting the Init LCD Code.  Found the correct placement where the original was.  And thanks for the InitEncoder change.  That workaround should work great.  This also works with the 20x4 version of this display as well, just need to setup the display for those parameters.  Now, what to do with the extra screen real estate.

Closed 2017-10-14.

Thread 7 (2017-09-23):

xp machines not functioning

Druuka, 2017-09-23:
Per a discussion with Matt Pumplin on the ETC forums I think we should include this info on the readme.
I should also note that OSC over USB is not implemented / supported for Windows XP consoles and computers.

jpgagnon73, 2017-09-23:
Will XP machines ever be supported for USB/OSC?  It's a real shame to all the legacy consoles out there to not have this functionality, especially the Element owners out there.

bootress, 2017-09-25:
@MizPlusPlus can you weigh in on prospects for future XP support, before I update the README?

bootress, 2017-09-26:
I've been told Windows XP support is not planned for this project. I'll update the README shortly to reflect that.

Don't forget that [Element consoles are eligible for upgrade to Windows 7](http://www.etcconnect.com/Support/Articles/Windows-7-Upgrade-Eligibility.aspx), which will enable them to work with these devices.

Closed 2017-09-26.

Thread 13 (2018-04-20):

Nunchuck Calibration Issue

Jbithell, 2018-04-20:
## Inital Report

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

## Steps to debug
```
#include <Wire.h>
#include "WiiLib.h"

WiiChuck chuck = WiiChuck();

void setup() {
  Serial.begin(9600);
  chuck.begin();
  chuck.update();
  chuck.calibrateJoy();
}

void loop() {
  delay(20);
  chuck.update();

  Serial.print(chuck.readJoyX());
    Serial.print("    ");
  Serial.print(chuck.readJoyY());

    Serial.println();

}
```
If output of this script is anything other than 0,0 it's some kind of calibration issue.

https://github.com/Jbithell/lighthack/blob/f1b22f5b82649a9a4866627ea0ee4c63c39bea1f/user_projects/nunchuk/nunchuk_src/nunchuk_src.ino attempts to fix this - I'll get user to try it and then if fixes problem submit a PR

Jbithell, 2018-04-22:
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

Seems to be an issue with this particular chuck - but I was able to reproduce an issue whereby the uno booted before the chuck did causing a poor calibration (fixed by pressing device reset button) - fixes in pr https://github.com/ETCLabs/lighthack/pull/14

Closed 2018-04-25.

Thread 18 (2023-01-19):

no handshake on eos v3 startup

benjaminauer, 2023-01-19:
Handshake is not initiated when USB device is plugged in before eos v3 software is started.

eos v3 software does not scan for com ports on already plugged in usb devices.
usb devices always need to plugged in after the software is loaded.

MizPlusPlus, 2023-09-11:
Thanks @benjaminauer, we found the issue and will fix in Eos 3.2.4 🙏

Closed 2023-09-11.

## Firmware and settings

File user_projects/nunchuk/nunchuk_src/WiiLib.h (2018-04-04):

 /*
 * Nunchuck -- Use a Wii Nunchuck
 * Tim Hirzel http://www.growdown.com
 *
 notes on Wii Nunchuck Behavior.
 This library provides an improved derivation of rotation angles from the nunchuck accelerometer data.
 The biggest different over existing libraries (that I know of ) is the full 360 degrees of Roll data
 from teh combination of the x and z axis accelerometer data using the math library atan2.

 It is accurate with 360 degrees of roll (rotation around axis coming out of the c button, the front of the wii),
 and about 180 degrees of pitch (rotation about the axis coming out of the side of the wii).  (read more below)

 In terms of mapping the wii position to angles, its important to note that while the Nunchuck
 sense Pitch, and Roll, it does not sense Yaw, or the compass direction.  This creates an important
 disparity where the nunchuck only works within one hemisphere.  At a result, when the pitch values are
 less than about 10, and greater than about 170, the Roll data gets very unstable.  essentially, the roll
 data flips over 180 degrees very quickly.   To understand this property better, rotate the wii around the
 axis of the joystick.  You see the sensor data stays constant (with noise).  Because of this, it cant know
 the difference between arriving upside via 180 degree Roll, or 180 degree pitch.  It just assumes its always
 180 roll.


 *
 * This file is an adaptation of the code by these authors:
 * Tod E. Kurt, http://todbot.com/blog/
 *
 * The Wii Nunchuck reading code is taken from Windmeadow Labs
 * http://www.windmeadow.com/node/42
 *
 * Conversion to Arduino 1.0 by Danjovic
 * http://hotbit.blogspot.com
 *
 * Included the Fix from Martin Peris by Leopold Klimesch
 * http://blog.martinperis.com/2011/04/arduino-wiichuck.html
 *
 *
 */

#ifndef WiiChuck_h
#define WiiChuck_h

#include "Arduino.h"
#include <Wire.h>
#include <math.h>


// these may need to be adjusted for each nunchuck for calibration
#define ZEROX 510  
#define ZEROY 490
#define ZEROZ 460
#define RADIUS 210  // probably pretty universal

#define DEFAULT_ZERO_JOY_X 124
#define DEFAULT_ZERO_JOY_Y 132

//Set the power pins for the wiichuck, otherwise it will not be powered up
#define pwrpin PORTC3
#define gndpin PORTC2


class WiiChuck {
    private:
        uint8_t cnt;
        uint8_t status[6];              // array to store wiichuck output
        uint8_t averageCounter;
        //int accelArray[3][AVERAGE_N];  // X,Y,Z
        int i;
        int total;
        uint8_t zeroJoyX;   // these are about where mine are
        uint8_t zeroJoyY; // use calibrateJoy when the stick is at zero to correct
        int lastJoyX;
        int lastJoyY;
        int angles[3];

        bool lastZ, lastC;


    public:

        uint8_t joyX;
        uint8_t joyY;
        bool buttonZ;
        bool buttonC;
        void begin()
        {
      //Set power pinds
            DDRC |= _BV(pwrpin) | _BV(gndpin);

            PORTC &=~ _BV(gndpin);

            PORTC |=  _BV(pwrpin);

            delay(100);  // wait for things to stabilize   


            //send initialization handshake
            Wire.begin();
            cnt = 0;
            averageCounter = 0;
            // instead of the common 0x40 -> 0x00 initialization, we
            // use 0xF0 -> 0x55 followed by 0xFB -> 0x00.
            // this lets us use 3rd party nunchucks (like cheap $4 ebay ones)
            // while still letting us use official oness.
            // only side effect is that we no longer need to decode bytes in _nunchuk_decode_byte
            // seehttp://forum.arduino.cc/index.php?topic=45924#msg333160
            //  
            Wire.beginTransmission(0x52);       // device address
            Wire.write(0xF0);
            Wire.write(0x55);
            Wire.endTransmission();
            delay(1);
            Wire.beginTransmission(0x52);
            Wire.write(0xFB);
            Wire.write((uint8_t)0x00);

            Wire.endTransmission();
            update();            
            for (i = 0; i<3;i++) {
                angles[i] = 0;
            }
            zeroJoyX = DEFAULT_ZERO_JOY_X;
            zeroJoyY = DEFAULT_ZERO_JOY_Y;
        }


        void calibrateJoy() {
            zeroJoyX = joyX;
            zeroJoyY = joyY;
        }

        void update() {

            Wire.requestFrom (0x52, 6); // request data from nunchuck
            while (Wire.available ()) {
                // receive byte as an integer
                status[cnt] = _nunchuk_decode_byte (Wire.read()); //
                cnt++;
            }
            if (cnt > 5) {
                lastZ = buttonZ;
                lastC = buttonC;
                lastJoyX = readJoyX();
                lastJoyY = readJoyY();
                //averageCounter ++;
                //if (averageCounter >= AVERAGE_N)
                //    averageCounter = 0;

                cnt = 0;
                joyX = (status[0]);
                joyY = (status[1]);
                for (i = 0; i < 3; i++)
                    //accelArray[i][averageCounter] = ((int)status[i+2] << 2) + ((status[5] & (B00000011 << ((i+1)*2) ) >> ((i+1)*2)));
                    angles[i] = (status[i+2] << 2) + ((status[5] & (B00000011 << ((i+1)*2) ) >> ((i+1)*2)));

                //accelYArray[averageCounter] = ((int)status[3] << 2) + ((status[5] & B00110000) >> 4);
                //accelZArray[averageCounter] = ((int)status[4] << 2) + ((status[5] & B11000000) >> 6);

                buttonZ = !( status[5] & B00000001);
                buttonC = !((status[5] & B00000010) >> 1);
                _send_zero(); // send the request for next bytes

            }
        }


    // UNCOMMENT FOR DEBUGGING
    //byte * getStatus() {
    //    return status;
    //}

    float readAccelX() {
       // total = 0; // accelArray[xyz][averageCounter] * FAST_WEIGHT;
        return (float)angles[0] - ZEROX;
    }
    float readAccelY() {
        // total = 0; // accelArray[xyz][averageCounter] * FAST_WEIGHT;
        return (float)angles[1] - ZEROY;
    }
    float readAccelZ() {
        // total = 0; // accelArray[xyz][averageCounter] * FAST_WEIGHT;
        return (float)angles[2] - ZEROZ;
    }

    bool zPressed() {
        return (buttonZ && ! lastZ);
    }
    bool cPressed() {
        return (buttonC && ! lastC);
    }

    // for using the joystick like a directional button
    bool rightJoy(int thresh=60) {
        return (readJoyX() > thresh and lastJoyX <= thresh);
    }

    // for using the joystick like a directional button
    bool leftJoy(int thresh=60) {
        return (readJoyX() < -thresh and lastJoyX >= -thresh);
    }


    int readJoyX() {
        return (int) joyX - zeroJoyX;
    }

    int readJoyY() {
        return (int)joyY - zeroJoyY;
    }


    // R, the radius, generally hovers around 210 (at least it does with mine)
   // int R() {
   //     return sqrt(readAccelX() * readAccelX() +readAccelY() * readAccelY() + readAccelZ() * readAccelZ());  
   // }


    // returns roll degrees
    int readRoll() {
        return (int)(atan2(readAccelX(),readAccelZ())/ M_PI * 180.0);
    }

    // returns pitch in degrees
    int readPitch() {        
        return (int) (acos(readAccelY()/RADIUS)/ M_PI * 180.0);  // optionally swap 'RADIUS' for 'R()'
    }

    private:
        uint8_t _nunchuk_decode_byte (uint8_t x)
        {
            //decode is only necessary with certain initializations
            //x = (x ^ 0x17) + 0x17;
            return x;
        }

        void _send_zero()
        {
            Wire.beginTransmission (0x52);      // transmit to device 0x52
            Wire.write ((uint8_t)0x00);         // sends one byte
            Wire.endTransmission ();    // stop transmitting
        }

};


#endif

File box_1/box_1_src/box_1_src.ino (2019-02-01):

// Copyright (c) 2017 Electronic Theatre Controls, Inc., http://www.etcconnect.com
//
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

/*******************************************************************************

     Electronic Theatre Controls

     lighthack - Box 1

     (C) 2017-2018 by ETC


     This code implements a Pan/Tilt module using two encoders and three
     buttons. The two encoders function as pan and tilt controllers with one
     button being reserved for controlling fine/coarse mode. The other two
     buttons are assigned to Next and Last which make it easy to switch between
     channels.

 *******************************************************************************

    NOTE: UPDATE VERSION_STRING IN DEFINITIONS BELOW WHEN VERSION NUMBER CHANGES

    Revision History

    yyyy-mm-dd   Vxx      By_Who                 Comment

    2017-07-21   1.0.0.1  Ethan Oswald Massey    Original creation

    2017-10-19   1.0.0.2  Sam Kearney            Fix build errors on some
                                                 Arduino platforms. Change
                                                 OSC subscribe parameters

    2017-10-24   1.0.0.3  Sam Kearney            Add ability to scale encoder
                                                 output

    2017-11-22   1.0.0.4  Hans Hinrichsen        Add splash msg before Eos
                                                 connects

    2017-12-07   1.0.0.5  Hans Hinrichsen        Added timeout to disconnect
                                                 and show splash screen again

    2018-10-25   2.0.0.0  Richard Thompson       Generalised to support other
                                                 ETC consoles

    2018-10-25   2.0.0.1  Richard Thompson       Add basic support for ColorSource

 ******************************************************************************/

/*******************************************************************************
   Includes
 ******************************************************************************/
#include <OSCBoards.h>
#include <OSCBundle.h>
#include <OSCData.h>
#include <OSCMatch.h>
#include <OSCMessage.h>
#include <OSCTiming.h>
#ifdef BOARD_HAS_USB_SERIAL
#include <SLIPEncodedUSBSerial.h>
SLIPEncodedUSBSerial SLIPSerial(thisBoardsSerialUSB);
#else
#include <SLIPEncodedSerial.h>
SLIPEncodedSerial SLIPSerial(Serial);
#endif
#include <LiquidCrystal.h>
#include <string.h>

/*******************************************************************************
   Macros and Constants
 ******************************************************************************/
#define LCD_CHARS           16
#define LCD_LINES           2   // Currently assume at least 2 lines

#define NEXT_BTN            6
#define LAST_BTN            7
#define SHIFT_BTN           8

#define SUBSCRIBE           ((int32_t)1)
#define UNSUBSCRIBE         ((int32_t)0)

#define EDGE_DOWN           ((int32_t)1)
#define EDGE_UP             ((int32_t)0)

#define FORWARD             0
#define REVERSE             1

// Change these values to switch which direction increase/decrease pan/tilt
#define PAN_DIR             FORWARD
#define TILT_DIR            FORWARD

// Use these values to make the encoder more coarse or fine.
// This controls the number of wheel "ticks" the device sends to the console
// for each tick of the encoder. 1 is the default and the most fine setting.
// Must be an integer.
#define PAN_SCALE           1
#define TILT_SCALE          1

#define SIG_DIGITS          3   // Number of significant digits displayed

#define OSC_BUF_MAX_SIZE    512

const String HANDSHAKE_QUERY = "ETCOSC?";
const String HANDSHAKE_REPLY = "OK";

//See displayScreen() below - limited to 10 chars (after 6 prefix chars)
#define VERSION_STRING      "2.0.0.1"

#define BOX_NAME_STRING     "box1"

// Change these values to alter how long we wait before sending an OSC ping
// to see if Eos is still there, and then finally how long before we
// disconnect and show the splash screen
// Values are in milliseconds
#define PING_AFTER_IDLE_INTERVAL    2500
#define TIMEOUT_AFTER_IDLE_INTERVAL 5000

/*******************************************************************************
   Local Types
 ******************************************************************************/
enum WHEEL_TYPE { TILT, PAN };
enum WHEEL_MODE { COARSE, FINE };

struct Encoder
{
  uint8_t pinA;
  uint8_t pinB;
  int pinAPrevious;
  int pinBPrevious;
  float pos;
  uint8_t direction;
};
struct Encoder panWheel;
struct Encoder tiltWheel;

enum ConsoleType
{
  ConsoleNone,
  ConsoleEos,
  ConsoleCobalt,
  ConsoleColorSource
};

/*******************************************************************************
   Global Variables
 ******************************************************************************/

// initialize the library with the numbers of the interface pins
LiquidCrystal lcd(12, 11, 5, 4, 3, 2);

bool updateDisplay = false;
ConsoleType connectedToConsole = ConsoleNone;
unsigned long lastMessageRxTime = 0;
bool timeoutPingSent = false;

/*******************************************************************************
   Local Functions
 ******************************************************************************/

/*******************************************************************************
   Issues all our subscribes to Eos. When subscribed, Eos will keep us updated
   with the latest values for a given parameter.

   Parameters:  none

   Return Value: void

 ******************************************************************************/
void issueEosSubscribes()
{
  // Add a filter so we don't get spammed with unwanted OSC messages from Eos
  OSCMessage filter("/eos/filter/add");
  filter.add("/eos/out/param/*");
  filter.add("/eos/out/ping");
  SLIPSerial.beginPacket();
  filter.send(SLIPSerial);
  SLIPSerial.endPacket();

  // subscribe to Eos pan & tilt updates
  OSCMessage subPan("/eos/subscribe/param/pan");
  subPan.add(SUBSCRIBE);
  SLIPSerial.beginPacket();
  subPan.send(SLIPSerial);
  SLIPSerial.endPacket();

  OSCMessage subTilt("/eos/subscribe/param/tilt");
  subTilt.add(SUBSCRIBE);
  SLIPSerial.beginPacket();
  subTilt.send(SLIPSerial);
  SLIPSerial.endPacket();
}

/*******************************************************************************
   Given a valid OSCMessage (relevant to Pan/Tilt), we update our Encoder struct
   with the new position information.

   Parameters:
    msg - The OSC message we will use to update our internal data
    addressOffset - Unused (allows for multiple nested roots)

   Return Value: void

 ******************************************************************************/
void parseFloatPanUpdate(OSCMessage& msg, int addressOffset)
{
  panWheel.pos = msg.getOSCData(0)->getFloat();
  updateDisplay = true;
}

void parseFloatTiltUpdate(OSCMessage& msg, int addressOffset)
{
  tiltWheel.pos = msg.getOSCData(0)->getFloat();
  updateDisplay = true;
}

void parseEos(OSCMessage& msg, int addressOffset)
{
  // If we don't think we're connected, reconnect and subscribe
  if (connectedToConsole != ConsoleEos)
  {
    issueEosSubscribes();
    connectedToConsole = ConsoleEos;
    updateDisplay = true;
  }

  if (!msg.route("/out/param/pan", parseFloatPanUpdate, addressOffset))
    msg.route("/out/param/tilt", parseFloatTiltUpdate, addressOffset);
}

/******************************************************************************/

void parseCobalt(OSCMessage& msg, int addressOffset)
{
  // Cobalt doesn't currently send anything other than ping
  connectedToConsole = ConsoleCobalt;
  updateDisplay = true;
}

void parseColorSource(OSCMessage& msg, int addressOffset)
{
  // ColorSource doesn't currently send anything other than ping
  connectedToConsole = ConsoleColorSource;
  updateDisplay = true;
}

/*******************************************************************************
   Given an unknown OSC message we check to see if it's a handshake message.
   If it's a handshake we issue a subscribe, otherwise we begin route the OSC
   message to the appropriate function.

   Parameters:
    msg - The OSC message of unknown importance

   Return Value: void

 ******************************************************************************/
void parseOSCMessage(String& msg)
{
  // check to see if this is the handshake string
  if (msg.indexOf(HANDSHAKE_QUERY) != -1)
  {
    // handshake string found!
    SLIPSerial.beginPacket();
    SLIPSerial.write((const uint8_t*)HANDSHAKE_REPLY.c_str(), (size_t)HANDSHAKE_REPLY.length());
    SLIPSerial.endPacket();

    // An Eos would do nothing until subscribed
    // Let Eos know we want updates on some things
    issueEosSubscribes();

    updateDisplay = true;
  }
  else
  {
    // prepare the message for routing by filling an OSCMessage object with our message string
    OSCMessage oscmsg;
    oscmsg.fill((uint8_t*)msg.c_str(), (int)msg.length());
    // route pan/tilt messages to the relevant update function

    // Try the various OSC routes
    if (oscmsg.route("/eos", parseEos))
      return;
    if (oscmsg.route("/cobalt", parseCobalt))
      return;
    if (oscmsg.route("/cs", parseColorSource))
      return;
  }
}

/*******************************************************************************
   Updates the display with the latest pan and tilt positions.

   Parameters:  none

   Return Value: void

 ******************************************************************************/
void displayStatus()
{
  lcd.clear();

  switch (connectedToConsole)
  {
    case ConsoleNone:
      {
        // display a splash message before the Eos connection is open
        lcd.setCursor(0, 0);
        lcd.print(BOX_NAME_STRING " v" VERSION_STRING);
        lcd.setCursor(0, 1);
        lcd.print("Waiting...");
      } break;

    case ConsoleEos:
      {
        // put the cursor at the begining of the first line
        lcd.setCursor(0, 0);
        lcd.print("Pan:  ");
        lcd.print(panWheel.pos, SIG_DIGITS);

        // put the cursor at the begining of the second line
        lcd.setCursor(0, 1);
        lcd.print("Tilt: ");
        lcd.print(tiltWheel.pos, SIG_DIGITS);
      } break;

    case ConsoleCobalt:
      {
        lcd.setCursor(7, 0);
        lcd.print("Cobalt");
        lcd.setCursor(0, 1);
        lcd.print("Pan");
        lcd.setCursor(12, 1);
        lcd.print("Tilt");
      } break;

    case ConsoleColorSource:
      {
        lcd.setCursor(2, 0);
        lcd.print("ColorSource");
        lcd.setCursor(0, 1);
        lcd.print("Pan");
        lcd.setCursor(12, 1);
        lcd.print("Tilt");
      } break;

  }

  updateDisplay = false;
}

/*******************************************************************************
   Initializes a given encoder struct to the requested parameters.

   Parameters:
    encoder - Pointer to the encoder we will be initializing
    pinA - Where the A pin is connected to the Arduino
    pinB - Where the B pin is connected to the Arduino
    direction - Determines if clockwise or counterclockwise is "forward"

   Return Value: void

 ******************************************************************************/
void initEncoder(struct Encoder* encoder, uint8_t pinA, uint8_t pinB, uint8_t direction)
{
  encoder->pinA = pinA;
  encoder->pinB = pinB;
  encoder->pos = 0;
  encoder->direction = direction;

  pinMode(pinA, INPUT_PULLUP);
  pinMode(pinB, INPUT_PULLUP);

  encoder->pinAPrevious = digitalRead(pinA);
  encoder->pinBPrevious = digitalRead(pinB);
}

/*******************************************************************************
   Checks if the encoder has moved by comparing the previous state of the pins
   with the current state. If they are different, we know there is movement.
   In the event of movement we update the current state of our pins.

   Parameters:
    encoder - Pointer to the encoder we will be checking for motion

   Return Value:
    encoderMotion - Returns the 0 if the encoder has not moved
                                1 for forward motion
                               -1 for reverse motion

 ******************************************************************************/
int8_t updateEncoder(struct Encoder* encoder)
{
  int8_t encoderMotion = 0;
  int pinACurrent = digitalRead(encoder->pinA);
  int pinBCurrent = digitalRead(encoder->pinB);

  // has the encoder moved at all?
  if (encoder->pinAPrevious != pinACurrent)
  {
    // Since it has moved, we must determine if the encoder has moved forwards or backwards
    encoderMotion = (encoder->pinAPrevious == encoder->pinBPrevious) ? -1 : 1;

    // If we are in reverse mode, flip the direction of the encoder motion
    if (encoder->direction == REVERSE)
      encoderMotion = -encoderMotion;
  }
  encoder->pinAPrevious = pinACurrent;
  encoder->pinBPrevious = pinBCurrent;

  return encoderMotion;
}

/*******************************************************************************
   Sends a message to Eos informing them of a wheel movement.

   Parameters:
    type - the type of wheel that's moving (i.e. pan or tilt)
    ticks - the direction and intensity of the movement

   Return Value: void

 ******************************************************************************/

void sendOscMessage(const String &address, float value)
{
  OSCMessage msg(address.c_str());
  msg.add(value);
  SLIPSerial.beginPacket();
  msg.send(SLIPSerial);
  SLIPSerial.endPacket();
}

void sendEosWheelMove(WHEEL_TYPE type, float ticks)
{
  String wheelMsg("/eos/wheel");

  if (digitalRead(SHIFT_BTN) == LOW)
    wheelMsg.concat("/fine");
  else
    wheelMsg.concat("/coarse");

  if (type == PAN)
    wheelMsg.concat("/pan");
  else if (type == TILT)
    wheelMsg.concat("/tilt");
  else
    // something has gone very wrong
    return;

  sendOscMessage(wheelMsg, ticks);
}

void sendCobaltWheelMove(WHEEL_TYPE type, float ticks)
{
  String wheelMsg("/cobalt/param");

  if (type == PAN)
    wheelMsg.concat("/pan/wheel");
  else if (type == TILT)
    wheelMsg.concat("/tilt/wheel");
  else
    // something has gone very wrong
    return;

  if (digitalRead(SHIFT_BTN) != LOW)
    ticks = ticks * 16;

  sendOscMessage(wheelMsg, ticks);
}

void sendColorSourceWheelMove(WHEEL_TYPE type, float ticks)
{
  String wheelMsg("/cs/param");

  if (type == PAN)
    wheelMsg.concat("/pan/wheel");
  else if (type == TILT)
    wheelMsg.concat("/tilt/wheel");
  else
    // something has gone very wrong
    return;

  if (digitalRead(SHIFT_BTN) != LOW)
    ticks = ticks * 2;

  sendOscMessage(wheelMsg, ticks);
}

/******************************************************************************/

void sendWheelMove(WHEEL_TYPE type, float ticks)
{
  switch (connectedToConsole)
  {
    default:
    case ConsoleEos:
      sendEosWheelMove(type, ticks);
      break;
    case ConsoleCobalt:
      sendCobaltWheelMove(type, ticks);
      break;
    case ConsoleColorSource:
      sendColorSourceWheelMove(type, ticks);
      break;
  }
}

/*******************************************************************************
   Sends a message to the console informing them of a key press.

   Parameters:
    down - whether a key has been pushed down (true) or released (false)
    key - the OSC key name that has moved

   Return Value: void

 ******************************************************************************/
void sendKeyPress(bool down, const String &key)
{
  String keyAddress;
  switch (connectedToConsole)
  {
    default:
    case ConsoleEos:
      keyAddress = "/eos/key/" + key;
      break;
    case ConsoleCobalt:
      keyAddress = "/cobalt/key/" + key;
      break;
    case ConsoleColorSource:
      keyAddress = "/cs/key/" + key;
      break;
  }
  OSCMessage keyMsg(keyAddress.c_str());

  if (down)
    keyMsg.add(EDGE_DOWN);
  else
    keyMsg.add(EDGE_UP);

  SLIPSerial.beginPacket();
  keyMsg.send(SLIPSerial);
  SLIPSerial.endPacket();
}

/*******************************************************************************
   Checks the status of all the relevant buttons (i.e. Next & Last)

   NOTE: This does not check the shift key. The shift key is used in tandem with
   the encoder to determine coarse/fine mode and thus does not report directly.

   Parameters: none

   Return Value: void

 ******************************************************************************/

void checkButtons()
{
  // OSC configuration
  const int keyCount = 2;
  const int keyPins[2] = {NEXT_BTN, LAST_BTN};
  const String keyNames[4] = {
    "NEXT", "LAST",
    "soft6", "soft4"
  };

  static int keyStates[2] = {HIGH, HIGH};

  // Eos and Cobalt buttons are the same
  // ColorSource is different
  int firstKey = (connectedToConsole == ConsoleColorSource) ? 2 : 0;

  // Loop over the buttons
  for (int keyNum = 0; keyNum < keyCount; ++keyNum)
  {
    // Has the button state changed
    if (digitalRead(keyPins[keyNum]) != keyStates[keyNum])
    {
      // Notify console of this key press
      if (keyStates[keyNum] == LOW)
      {
        sendKeyPress(false, keyNames[firstKey + keyNum]);
        keyStates[keyNum] = HIGH;
      }
      else
      {
        sendKeyPress(true, keyNames[firstKey + keyNum]);
        keyStates[keyNum] = LOW;
      }
    }
  }
}

/*******************************************************************************
   Here we setup our encoder, lcd, and various input devices. We also prepare
   to communicate OSC with Eos by setting up SLIPSerial. Once we are done with
   setup() we pass control over to loop() and never call setup() again.

   NOTE: This function is the entry function. This is where control over the
   Arduino is passed to us (the end user).

   Parameters: none

   Return Value: void

 ******************************************************************************/
void setup()
{
  SLIPSerial.begin(115200);
  // This is a hack around an Arduino bug. It was taken from the OSC library
  //examples
#ifdef BOARD_HAS_USB_SERIAL
  while (!SerialUSB);
#else
  while (!Serial);
#endif

  // This is necessary for reconnecting a device because it needs some time
  // for the serial port to open. The handshake message may have been sent
  // from the console before #lighthack was ready

  SLIPSerial.beginPacket();
  SLIPSerial.write((const uint8_t*)HANDSHAKE_REPLY.c_str(), (size_t)HANDSHAKE_REPLY.length());
  SLIPSerial.endPacket();

  // If it's an Eos, request updates on some things
  issueEosSubscribes();

  initEncoder(&panWheel, A0, A1, PAN_DIR);
  initEncoder(&tiltWheel, A3, A4, TILT_DIR);

  lcd.begin(LCD_CHARS, LCD_LINES);
  lcd.clear();

  pinMode(NEXT_BTN, INPUT_PULLUP);
  pinMode(LAST_BTN, INPUT_PULLUP);
  pinMode(SHIFT_BTN, INPUT_PULLUP);

  displayStatus();
}

/*******************************************************************************
   Here we service, monitor, and otherwise control all our peripheral devices.
   First, we retrieve the status of our encoders and buttons and update Eos.
   Next, we check if there are any OSC messages for us.
   Finally, we update our display (if an update is necessary)

   NOTE: This function is our main loop and thus this function will be called
   repeatedly forever

   Parameters: none

   Return Value: void

 ******************************************************************************/
void loop()
{
  static String curMsg;
  int size;
  // get the updated state of each encoder
  int32_t panMotion = updateEncoder(&panWheel);
  int32_t tiltMotion = updateEncoder(&tiltWheel);

  // Scale the result by a scaling factor
  panMotion *= PAN_SCALE;
  tiltMotion *= TILT_SCALE;

  // check for next/last updates
  checkButtons();

  // now update our wheels
  if (tiltMotion != 0)
    sendWheelMove(TILT, tiltMotion);

  if (panMotion != 0)
    sendWheelMove(PAN, panMotion);

  // Then we check to see if any OSC commands have come from Eos
  // and update the display accordingly.
  size = SLIPSerial.available();
  if (size > 0)
  {
    // Fill the msg with all of the available bytes
    while (size--)
      curMsg += (char)(SLIPSerial.read());
  }
  if (SLIPSerial.endofPacket())
  {
    parseOSCMessage(curMsg);
    lastMessageRxTime = millis();
    // We only care about the ping if we haven't heard recently
    // Clear flag when we get any traffic
    timeoutPingSent = false;
    curMsg = String();
  }

  if (lastMessageRxTime > 0)
  {
    unsigned long diff = millis() - lastMessageRxTime;
    //We first check if it's been too long and we need to time out
    if (diff > TIMEOUT_AFTER_IDLE_INTERVAL)
    {
      connectedToConsole = ConsoleNone;
      lastMessageRxTime = 0;
      updateDisplay = true;
      timeoutPingSent = false;
    }

    //It could be the console is sitting idle. Send a ping once to
    // double check that it's still there, but only once after 2.5s have passed
    if (!timeoutPingSent && diff > PING_AFTER_IDLE_INTERVAL)
    {
      OSCMessage ping("/eos/ping");
      ping.add(BOX_NAME_STRING "_hello"); // This way we know who is sending the ping
      SLIPSerial.beginPacket();
      ping.send(SLIPSerial);
      SLIPSerial.endPacket();
      timeoutPingSent = true;
    }
  }

  if (updateDisplay)
    displayStatus();
}

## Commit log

2017-07-18 Add face plate template and wiring diagram
2017-07-22 Add assembly instructions document.
2017-07-26 Add /eos/filter functionality
2017-08-03 USB reconnection
    Solves the problem with reconnection of an usb device.
2017-08-03 Arduino with native USB
    Allows the use of Arduinos with native usb device like Leonardo
2017-08-14 delete deprecated macro
    the macro #if ARDUINO >= 100 is no more necessary because there is no more IDE version < 100 is available since some years
2017-08-26 Addition in setup() for Arduino with native USB
    The addition is necessary to get Arduino with native USB (like Leonardo or Micro) to work properly.
2017-10-19 v1.0.0.2
    Change which pan/tilt params are being read from Eos
    Fix for non-compiling sketches on some version of the Arduino IDE
    Spelling and grammar pass :wink:
2017-10-20 Fix bug compiling on other versions of Arduino IDE.
    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
    [usb_test_sketch.ino]
2017-11-02 Update assembly instructions and wiring diagram
2017-12-07 Added timeout/ping mechanism (#9)
    * Version 1.0.0.5 - Added timeout/ping mechanism
    If we haven't received a packet in 2500 ms, send a quick ping
    If Eos doesn't send anything after a cumulative 5000ms, disconnect
    and reset the splash screen
    [box_1_src.ino]
2017-12-07 Add faceplate 3D model for 3D printing
    [faceplate_model.STL]
2017-12-14 Add blank faceplate 3D model
    [faceplate_model_blank.STL]
2018-04-04 Add assembly instructions
2018-04-04 Tweak button settings
2018-04-04 Tweak timings to deal with https://github.com/Jbithell/lighthack/issues/1
    [nunchuk_src.ino]
2018-04-20 Apply a manual correction factor as for some reason the library provided calibration can be unreliable (see https://github.com/ETCLabs/lighthack/issues/13 )
    Requires further investigation
    [nunchuk_src.ino]
2018-04-21 Wait 2 seconds to ensure chuck fully booted and working before running check - fixed reproducable issue in https://github.com/ETCLabs/lighthack/issues/13
    [nunchuk_src.ino]
2018-05-21 Update README.md to reflect current status of macOS support (supported!)
2018-11-28 Revert "Merge pull request #15 from RichardTea/master"
    This reverts commit 0eb7a8e86fa9b48114f73faddde52509255b0723, reversing
    changes made to 313107dd70272c468974793d9923e9defb5100f4.
    [box_1_src.ino]
2019-02-01 Undo the revert (re-revert?) of pull #15.
    This reverts commit b123d34ffc0d3c5ef1813e57a4288a7ccd23caa0.
    [box_1_src.ino]
